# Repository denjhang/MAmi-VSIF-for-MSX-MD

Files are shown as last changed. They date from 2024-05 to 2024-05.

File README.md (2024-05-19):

# MAmi-VSIF for MSX+MD
 The open source hardware implementation of the VSIF standard can be completed using the red FT232 module that can be easily purchased on Alex. No complicated welding is required. The current hardware supports both MSX and MD devices.    
 The currently supported software is VGM player and MamidiMEMO. For details, see here:   
 https://github.com/110-kenichi/mame  
## Connect to 1ChipMSX (clone)  
The latest version of the vgmplay program fully supports 1ChipMSX's PSG+OPLL+SCC1, but it needs to be used in a certain order to be used normally. First use mini usb to connect to the FTDI module, then open vgmplay. At this time, first check whether the words "usb serial port (com7)" appear in the device manager. If not, you need to install the driver.  
  
After the computer correctly recognizes FTDI, the next step is to open your 1ChipMSX, and then use sofarun to open VGMPlay_msx.rom and run the rom according to the default settings.  
At this time, msx will have a black screen background with "MAMI VGM Sound Driver", and then you can see that the OPLL and SCC of your 1ChipMSX have been correctly recognized and the device location is displayed. At this time, plug the DB9 female connector of VSIF into the JoyPort2 of 1ChipMSX, and the connection is successful without pressing any buttons.  
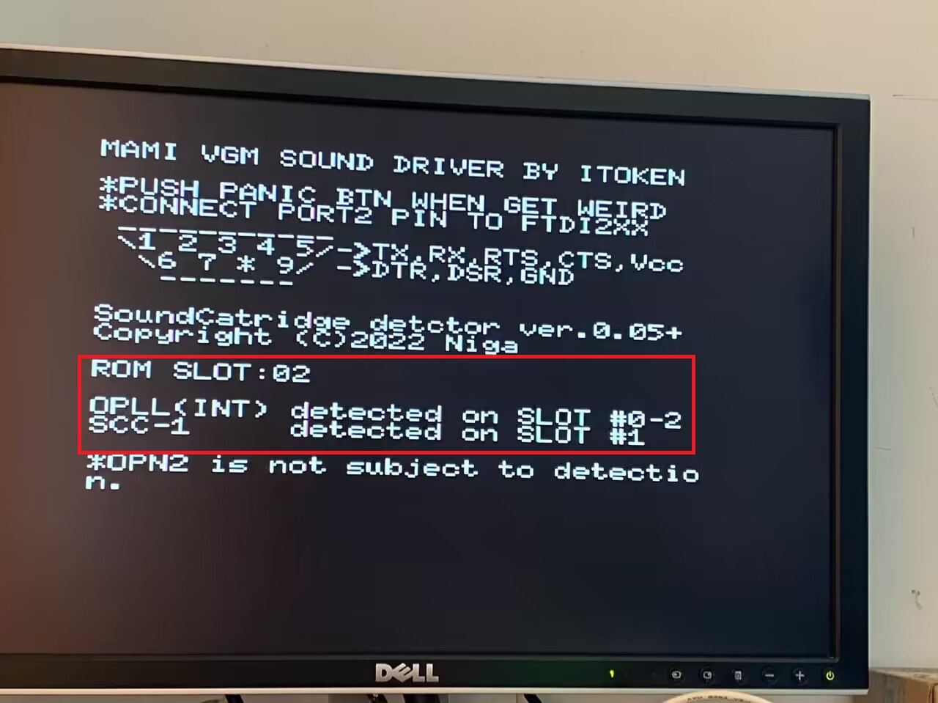
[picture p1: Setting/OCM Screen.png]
  
Then set the VSIF Checker according to the picture method. After the setting is completed, you can drag the vgm file into the VSIF Checker playlist. If the playback is very stuck, you need to adjust the FTDI CLK. I recommend adjusting it to 7/5/5. The playback speed is related to the length of the USB cable. It is not recommended to use a USB cable that is too long.    
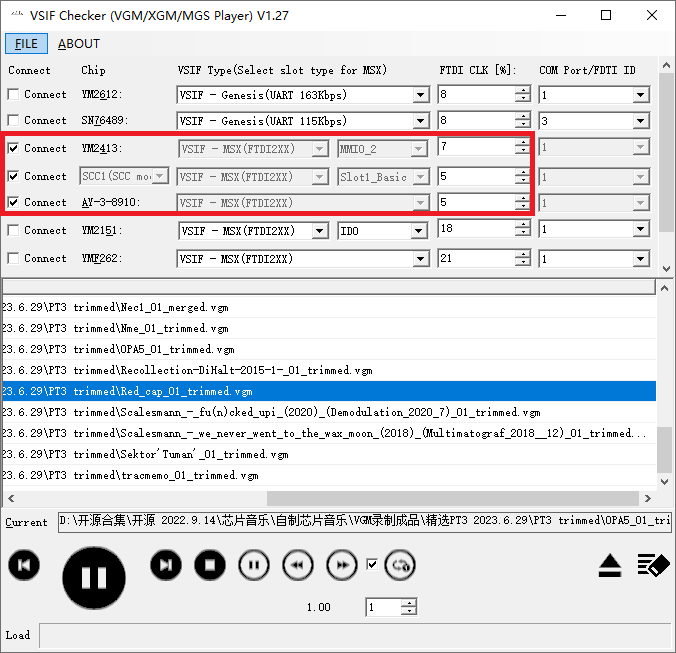
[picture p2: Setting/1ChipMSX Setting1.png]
    
It is best to use a new mini usb cable and avoid using old or rusty cables. Theoretically, the shorter the length of the USB cable, the faster the VSIF data transfer rate.

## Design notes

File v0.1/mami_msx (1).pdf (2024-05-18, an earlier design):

本書 PDF file

MSX / PC-6001 シリーズ対応 VGM Sound Interface
MAmi-VSIF dongle for MSX 使用説明書
猫の手リモコンもよろしく！ | Produced by にが HP
ご注意 | 本機は同人ハードウエアです。

ご使用には MSX または PC-6001 シリー

ズ本体と Windows10 以降の PC が必要
です。アフターサポートはありませんの
でご了承の上お求めください。
概要
MAmidiMEmo はレトロ PC やレトロゲーム、チッ プチューンなどで使われている FM 音源や PSG 音源 などを鳴らす事ができる Windows 用のソフトウエア MIDI 音源で、お使いの DAW や MIDI シーケンサー、 MIDI キーボードなどから FM 音源や PSG 音源を簡 単に鳴らすことが可能です。さらに、MAmidiMEmo が対応する実音源と PC とを USB で接続することで、 ソフトウエア音源の代わりに実音源を鳴らすことが
可能です。

本機は MSX/PC-6001 対応の MAmidiMEmo VGM

Sound Interface(VSIF)ドングルです。MSX/P6 に内 蔵、または接続された実音源を WindowsPC からデー タを流し込むことで発音させることができます。多数
の音源デバイスに対応しており、実音源による VGM
再生をお手軽にお楽しみいただけます。
対応機種

・MSX / PC-6001 シリーズ

・Windows10 以降の PC (32bit / 64bit 版）

MSX では MSX-DOS が動作する環境、または適当 な FlashROM カートリッジが必要です。
Windows8.1 以前の OS での動作は保証しません。

対応音源

・MSX 本体内蔵 PSG , MSX-MUSIC (OPLL)

・FMPAC (OPLL) , Konami SCC / SCC-I

・YAMAHA SFG-01 / SFG-05 (OPM)

・MSX-AUDIO (Y8950)

・Makoto compatible cartridge (OPNA)

・MusicalMemoryMapper (DCSG)

・似非 OPL3-RAM (OPL3)

・P6 本体内蔵 PSG , P6SR 内蔵 YM2203 (OPN)

・PC-60m55 cartridge (OPN)

・似非 P6ROM (OPN2)

各部の名称

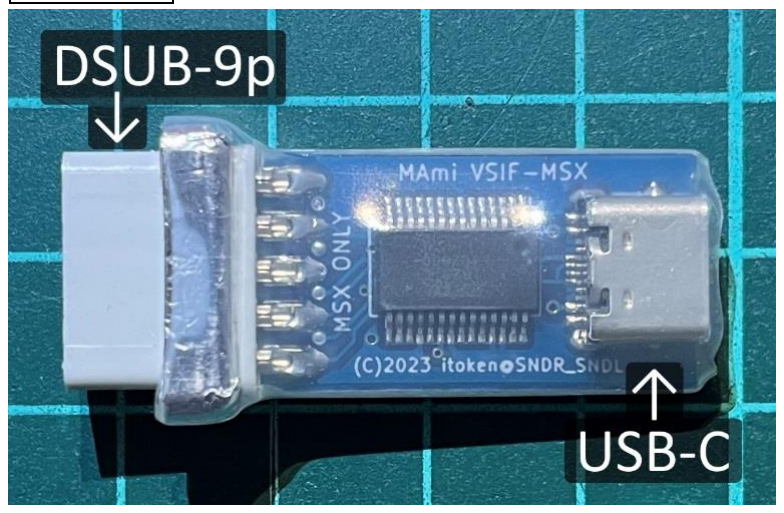
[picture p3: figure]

データ通信に対応した USB 2.0 Type-C ケーブルを別

途用意してください。

デバイス接続と FTDI ドライバのインストール
MSX/P6 に対応音源カートリッジを挿入し、本機を ジョイスティックポートに接続してください。MSX
では Port 2 に、P6 では Port 1 に接続します。

本機の USB-C コネクタと WindowsPC の USB 2.0 ポートをケーブル接続し、MSX/P6 の電源を投入する と、Windows が本機をシリアルポートデバイスとし て認識し、ドライバの自動インストールが行われます。

本機の電源は MSX/P6 から供給されます。そのため 本機を PC に接続しただけでは認識されません。

MAmidiMEmo アプリケーションのインストール 下記 URL から最新版の MAmidiMEmo パッケージ をダウンロードし、WindowsPC の適当なフォルダに 展開してください。

https://github.com/110-kenichi/mame/releases

MAmidiMEmo の動作には NET Framework 4.7 以

降と VC++2012 Runtime が必要です。

MAmi-VGM ドライバの起動

1) MSX-DOS から起動する場合
展開した MAmidiMEmo パッケージに含まれる 「VGM_msx.rom」と当方の製品サポートページ

http://niga2.sytes.net/sp/ から ダ ウ ン ロ ー ド した

「NGLOAD.COM」を MSX-DOS ディスクにコピー してください。MSX-DOS を起動し、下記コマンドを 実行すると MAmi-VGM ドライバが起動します。

NGLOAD VGM_MSX.ROM

2) MSX FlashROM から起動する場合

MAmidiMEmo パッケージ内の「VGM_msx.rom」 をお手持ちの FlashROM カートリッジに書き込み、 MSX スロットに挿入して電源を入れると自動的に

MAmi-VGM ドライバが起動します。FlashROM はな るべく番号の若いスロットに挿してください。

SoundCoreSLOT EX の内部拡張スロット#X-3 の FlashROM にインストールして運用することもでき

ます。この場合は「VGM_msx_Vkey.rom」を書き込 んでください。Vkey 版の ROM を使用した場合は MSX 起動時に V キーを押しっぱなしにすることで MAmi-VGM ドライバが起動します。V キーを押さな ければドライバの起動はスキップされます。

FlashROM デバイスへのインストール手順につい ては各製品のマニュアルを参照してください。

3) PC-6001 テープ（CMT）から LOAD する場合 PC の音声出力と PC-6001 の CMT 入力端子をケー

ブルで接続してください。PC-6001 を Mode1,Page1 で起動し、 CLOAD コマンド を実行 します。

MAmidiMEmoパッケージ内の「VGM_P6T_01.WAV」 を PC で再生し、LOAD が終わったら RUN します。

引き続き PC で「VGM_P6T_02.WAV」を再生し、 LOAD が完了すると MAmi-VGM ドライバが起動し ます。OPN 楽曲データを再生するデバイスの選択メ
ニューが表示されますので数字キーで選択すると画
面が消去され、VGM データ待ちとなります。

PSG 音源のみ接続されている場合は 1 を選択して ください。ロードに失敗する場合は PC の音声出力を 大きめに設定してやり直してください。

4) PC-6001 似非 P6ROM から起動する場合
PC で展開した MAmidiMEmo パッケージに含まれ

る「VGM_P6.ROM」を似非 P6ROM の FlashROM に書き込んで P6 のスロットに挿入し、電源を投入し てください。OPN 楽曲データを再生するデバイスの
選択メニューが表示されますので、数字キーで選択す
ると画面が消えて VGM データ待ちとなります。

VGM_P6.ROM を「戦士のカートリッジ」に書き込 んで運用することもできます。
各デバイスへの ROM ファイルの書き込み手順につ
いては製品のマニュアルを参照してください。

VGMPlayer の起動と VGM ファイルの再生

WindowsPC で VGMPlayer を起動し、GUI 画面に

て使用音源の VSIF Type を VSIF-MSX/PC-6001

(FTDI2XX)にして Connect します。このとき FTDI

CLK[%] =25、FTDI/COM No =1 に、FTDI Div ofst =0 に設定してください。Conn にチェックが入らない場 合は本機が正しく認識されていませんので、接続やド
ライバを確認してください。ファイルエリアにお好み
の VGM ファイルを登録して▶ボタンを押下すると再 生が始まります。演奏がもたつく場合は、FTDI
CLK[%]を少しずつ小さくします。発音されない場合 は MSX/P6 の再起動からやり直してください。

詳細は下記マニュアルを参してください。

https://github.com/110-kenichi/mame/blob/master

/docs/MAmidiMEmo/Manual.pdf (https://github.com/110-kenichi/mame/blob/master/docs/MAmidiMEmo/Manual.pdf)
技術情報

USB I/F : FT245RL (asynchronous bit bang mode)

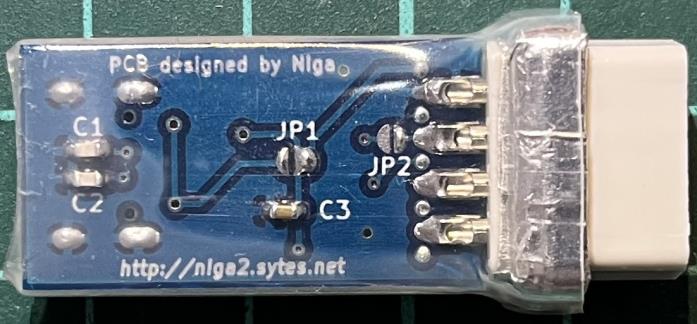
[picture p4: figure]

JP1 | 左 Close で USB から給電 右 Close で DSUB から給電 (default)
JP2 | Close で FT245RL-10p と DSUB-8p が接続 （default は Open）

FTDI CLK[%]や FTDI Div ofst の最適値には個体差 があります。いずれも数値が小さい方が高速です。

・謝辞ほか

itoken さん、MAmi-VGMPlayer の各種音源対応や

技術情報のご提供など、多大なるご協力ありがとうござ
いました。TINY 野郎さん、れふてぃさん、ゆうくんさ ん、ご協力ありがとうございました。

VGM Sound Interface（VSIF）は itoken さん発案に

よる音源デバイス用データ通信フォーマットです。
作者の WEB サイト

http://niga2.sytes.net 自宅サーバーのた

め時々落ちていることがあります。お問い

合わせは作者サイトの BBS か blog からお願いします。

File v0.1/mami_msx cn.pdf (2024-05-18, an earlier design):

### MSX 的 MAmi-VSIF 加密狗使⽤⼿册

概述

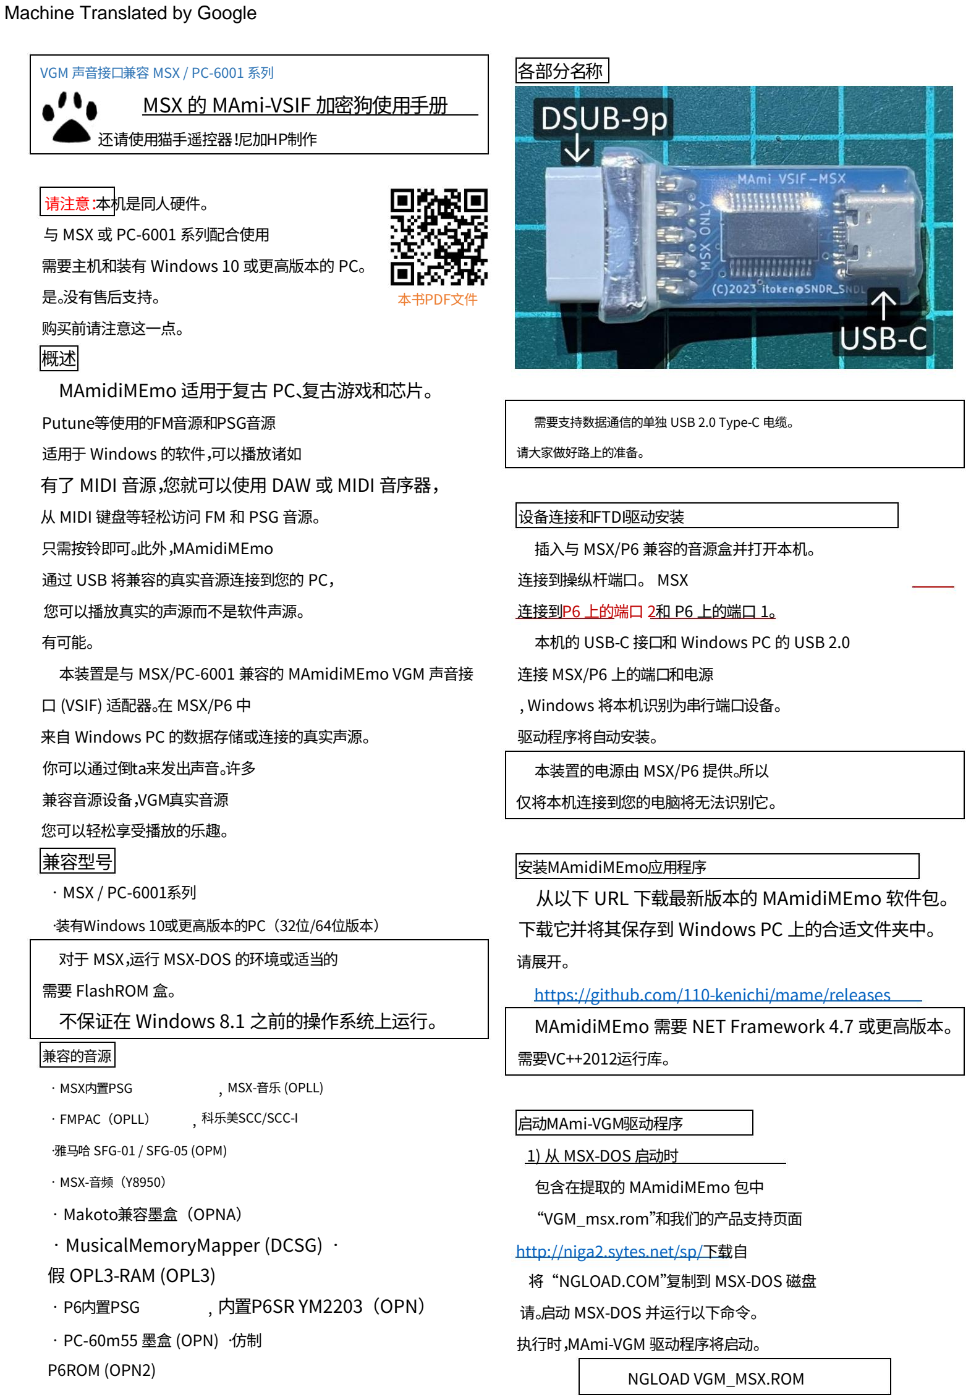
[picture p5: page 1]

本书PDF⽂件

需要⽀持数据通信的单独 USB 2.0 Type-C 电缆。

•FMPAC（OPLL）

,

,

请⼤家做好路上的准备。

科乐美SCC/SCC-I

•雅⻢哈 SFG-01 / SFG-05 (OPM)

•MSX-⾳频（Y8950）

•MSX内置PSG | MSX-⾳乐 (OPLL)

VGM 声⾳接⼝兼容 MSX / PC-6001 系列

http://niga2.sytes.net/sp/下载⾃

连接 MSX/P6 上的端⼝和电源

需要VC++2012运⾏库。

本装置的电源由 MSX/P6 提供。所以

有了 MIDI ⾳源，您就可以使⽤ DAW 或 MIDI ⾳序器，

内置P6SR YM2203（OPN）

需要 FlashROM 盒。

与 MSX 或 PC-6001 系列配合使⽤

连接到操纵杆端⼝。 MSX

Putune等使⽤的FM⾳源和PSG⾳源

•Makoto兼容墨盒（OPNA）

, Windows 将本机识别为串⾏端⼝设备。

### 下载它并将其保存到 Windows PC 上的合适⽂件夹中。

将“NGLOAD.COM”复制到 MSX-DOS 磁盘

安装MAmidiMEmo应⽤程序

本装置是与 MSX/PC-6001 兼容的 MAmidiMEmo VGM 声⾳接

⼝ (VSIF) 适配器。在 MSX/P6 中

,

仅将本机连接到您的电脑将⽆法识别它。

从 MIDI 键盘等轻松访问 FM 和 PSG ⾳源。

•MusicalMemoryMapper (DCSG) • 假 OPL3-RAM (OPL3)

请展开。

不保证在 Windows 8.1 之前的操作系统上运⾏。

连接到P6 上的端⼝ 2和 P6 上的端⼝ 1。

需要主机和装有 Windows 10 或更⾼版本的 PC。

启动MAmi-VGM驱动程序

您可以播放真实的声源⽽不是软件声源。

驱动程序将⾃动安装。

适⽤于 Windows 的软件，可以播放诸如

•MSX / PC-6001系列

执⾏时，MAmi-VGM 驱动程序将启动。

您可以轻松享受播放的乐趣。

### 各部分名称

MAmidiMEmo 适⽤于复古 PC、复古游戏和芯⽚。

只需按铃即可。此外，MAmidiMEmo

包含在提取的 MAmidiMEmo 包中

有可能。

是。没有售后⽀持。

兼容的⾳源

你可以通过倒ta来发出声⾳。许多

•P6内置PSG

https://github.com/110-kenichi/mame/releases

设备连接和FTDI驱动安装

还请使⽤猫⼿遥控器！尼加HP制作

1) 从 MSX-DOS 启动时

•装有Windows 10或更⾼版本的PC（32位/64位版本）

NGLOAD VGM_MSX.ROM

### 兼容型号

通过 USB 将兼容的真实⾳源连接到您的 PC，

•PC-60m55 墨盒 (OPN) •仿制

P6ROM (OPN2)

“VGM_msx.rom”和我们的产品⽀持⻚⾯

本机的 USB-C 接⼝和 Windows PC 的 USB 2.0

购买前请注意这⼀点。

对于 MSX，运⾏ MSX-DOS 的环境或适当的

MAmidiMEmo 需要 NET Framework 4.7 或更⾼版本。

兼容⾳源设备，VGM真实⾳源

请。启动 MSX-DOS 并运⾏以下命令。

从以下 URL 下载最新版本的 MAmidiMEmo 软件包。

来⾃ Windows PC 的数据存储或连接的真实声源。

插⼊与 MSX/P6 兼容的⾳源盒并打开本机。

请注意：本机是同⼈硬件。

## Machine Translated by Google

## Machine Translated by Google

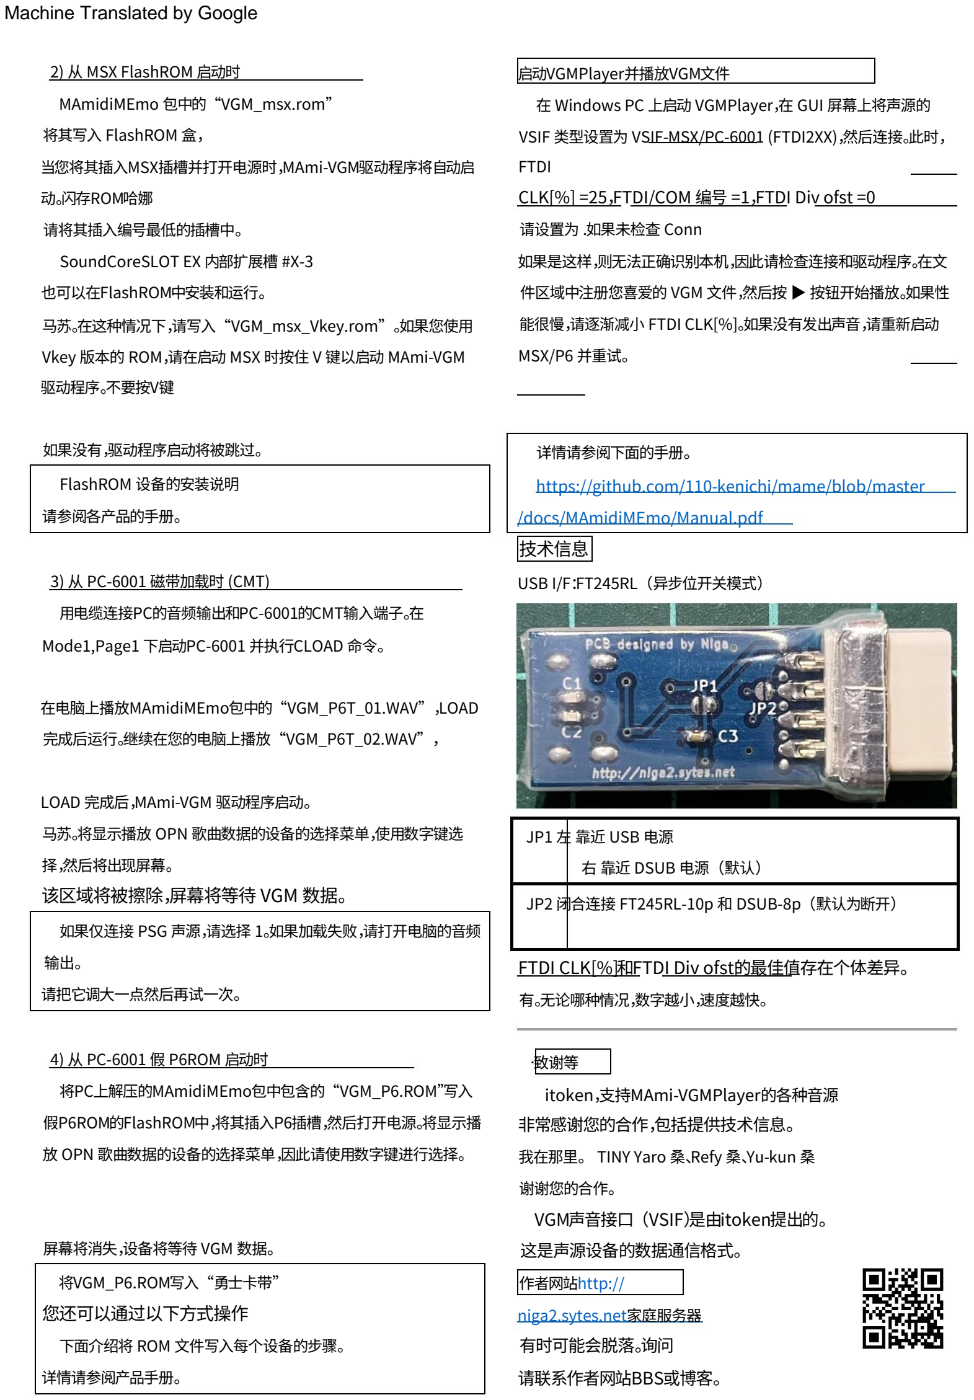
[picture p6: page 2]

itoken，⽀持MAmi-VGMPlayer的各种⾳源

### 有时可能会脱落。询问

### 请联系作者⽹站BBS或博客。

### ⾮常感谢您的合作，包括提供技术信息。

### 这是声源设备的数据通信格式。

VGM声⾳接⼝（VSIF）是由itoken提出的。

FTDI CLK[%]和FTDI Div ofst的最佳值存在个体差异。

⻢苏。在这种情况下，请写⼊“VGM_msx_Vkey.rom”。如果您使⽤

Vkey 版本的 ROM，请在启动 MSX 时按住 V 键以启动 MAmi-VGM

驱动程序。不要按V键

启动VGMPlayer并播放VGM⽂件

3) 从 PC-6001 磁带加载时 (CMT)

谢谢您的合作。

作者⽹站http://

niga2.sytes.net家庭服务器

请把它调⼤⼀点然后再试⼀次。

当您将其插⼊MSX插槽并打开电源时，MAmi-VGM驱动程序将⾃动启

动。闪存ROM哈娜

FlashROM 设备的安装说明

在电脑上播放MAmidiMEmo包中的“VGM_P6T_01.WAV”，LOAD

完成后运⾏。继续在您的电脑上播放“VGM_P6T_02.WAV”，

⻢苏。将显⽰播放 OPN 歌曲数据的设备的选择菜单，使⽤数字键选

择，然后将出现屏幕。

请设置为 .如果未检查 Conn

详情请参阅下⾯的⼿册。

如果是这样，则⽆法正确识别本机，因此请检查连接和驱动程序。在⽂

件区域中注册您喜爱的 VGM ⽂件，然后按 ▶ 按钮开始播放。如果性

能很慢，请逐渐减⼩ FTDI CLK[%]。如果没有发出声⾳，请重新启动

MSX/P6 并重试。

将其写⼊ FlashROM 盒，

4) 从 PC-6001 假 P6ROM 启动时

屏幕将消失，设备将等待 VGM 数据。

### 您还可以通过以下⽅式操作

右 靠近 DSUB 电源（默认）

2) 从 MSX FlashROM 启动时

⽤电缆连接PC的⾳频输出和PC-6001的CMT输⼊端⼦。在

Mode1,Page1 下启动PC-6001 并执⾏CLOAD 命令。

在 Windows PC 上启动 VGMPlayer，在 GUI 屏幕上将声源的

VSIF 类型设置为 VSIF-MSX/PC-6001 (FTDI2XX)，然后连接。此时，

FTDI

如果没有，驱动程序启动将被跳过。

SoundCoreSLOT EX 内部扩展槽 #X-3

/docs/MAmidiMEmo/Manual.pdf (https://github.com/110-kenichi/mame/blob/master/docs/MAmidiMEmo/Manual.pdf)

如果仅连接 PSG 声源，请选择 1。如果加载失败，请打开电脑的⾳频

输出。

详情请参阅产品⼿册。

USB I/F：FT245RL（异步位开关模式）

JP2 闭合连接 FT245RL-10p 和 DSUB-8p（默认为断开）

请参阅各产品的⼿册。

CLK[%] =25，FTDI/COM 编号 =1，FTDI Div ofst =0

LOAD 完成后，MAmi-VGM 驱动程序启动。

有。⽆论哪种情况，数字越⼩，速度越快。

我在那⾥。 TINY Yaro 桑、Refy 桑、Yu-kun 桑

将PC上解压的MAmidiMEmo包中包含的“VGM_P6.ROM”写⼊

假P6ROM的FlashROM中，将其插⼊P6插槽，然后打开电源。将显⽰播

放 OPN 歌曲数据的设备的选择菜单，因此请使⽤数字键进⾏选择。

•致谢等

https://github.com/110-kenichi/mame/blob/master

请将其插⼊编号最低的插槽中。

JP1 左 靠近 USB 电源

将VGM_P6.ROM写⼊“勇⼠卡带”

下⾯介绍将 ROM ⽂件写⼊每个设备的步骤。

也可以在FlashROM中安装和运⾏。

### 技术信息

MAmidiMEmo 包中的“VGM_msx.rom”

### 该区域将被擦除，屏幕将等待 VGM 数据。

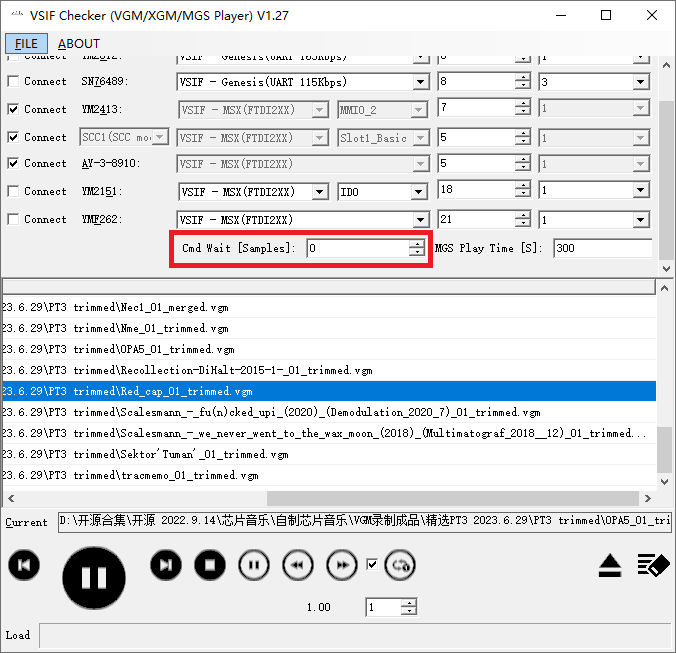
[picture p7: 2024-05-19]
Setting/1ChipMSX Setting2.png

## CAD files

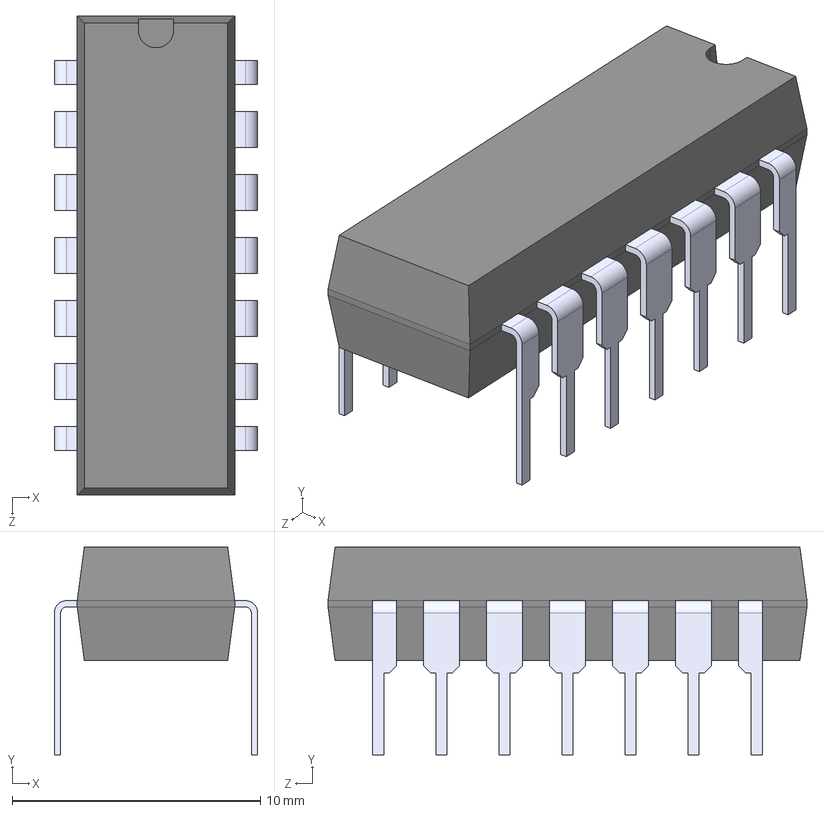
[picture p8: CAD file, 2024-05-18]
NES_MAmi/SN74LS00NE4/SN74LS00NE4.step
8.19 x 8.38 x 19.3 mm

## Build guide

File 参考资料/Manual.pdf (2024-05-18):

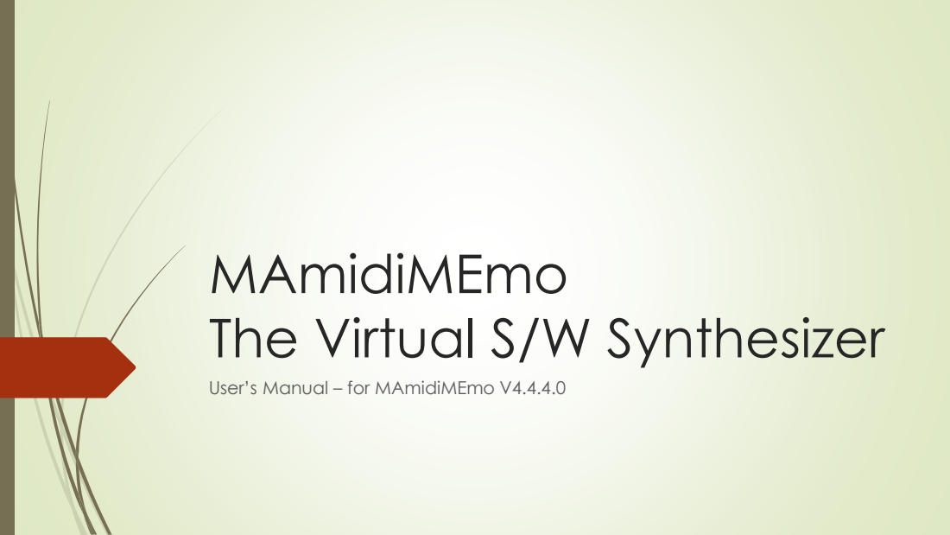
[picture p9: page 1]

MAmidiMEmo
The Virtual S/W Synthesizer

User’s Manual – for MAmidiMEmo V4.4.4.0

# What is the MAmidiMEmo?

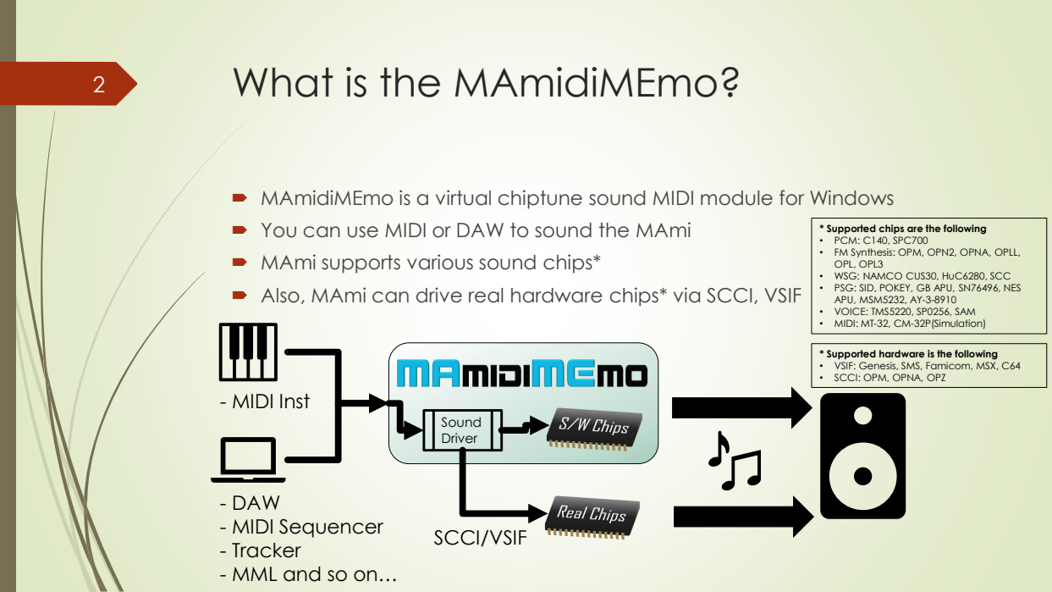
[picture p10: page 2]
- MIDI Inst; Sound Driver; SCCI/VSIF

MAmidiMEmo is a virtual chiptune sound MIDI module for Windows
You can use MIDI or DAW to sound the MAmi
MAmi supports various sound chips*
Also, MAmi can drive real hardware chips* via SCCI, VSIF

* Supported chips are the following
• PCM: C140, SPC700
• FM Synthesis: OPM, OPN2, OPNA, OPLL,
OPL, OPL3
• WSG: NAMCO CUS30, HuC6280, SCC
• PSG: SID, POKEY, GB APU, SN76496, NES
APU, MSM5232, AY-3-8910
• VOICE: TMS5220, SP0256, SAM
• MIDI: MT-32, CM-32P(Simulation)

* Supported hardware is the following
• VSIF: Genesis, SMS, Famicom, MSX, C64
• SCCI: OPM, OPNA, OPZ

- DAW
- MIDI Sequencer
- Tracker
- MML and so on…

# Install & Basic Settings

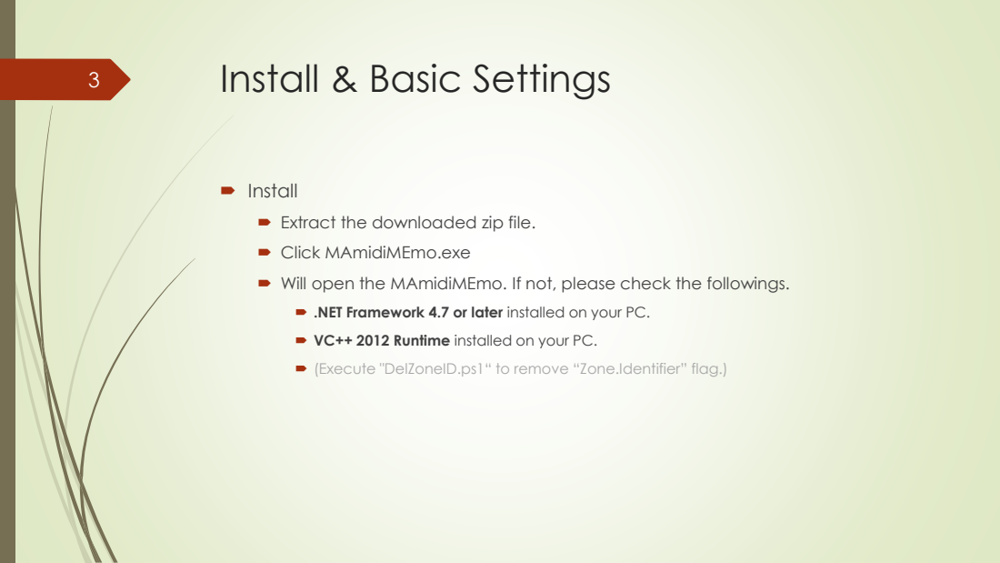
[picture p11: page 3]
Install

Extract the downloaded zip file.
Click MAmidiMEmo.exe
Will open the MAmidiMEmo. If not, please check the followings.

.NET Framework 4.7 or later installed on your PC.

VC++ 2012 Runtime installed on your PC.

(Execute "DelZoneID.ps1“ to remove “Zone.Identifier” flag.)

# Window Overview

# Add and Remove a Chip

To add
Select the chip
from this menu.

# Edit chip and sound parameters

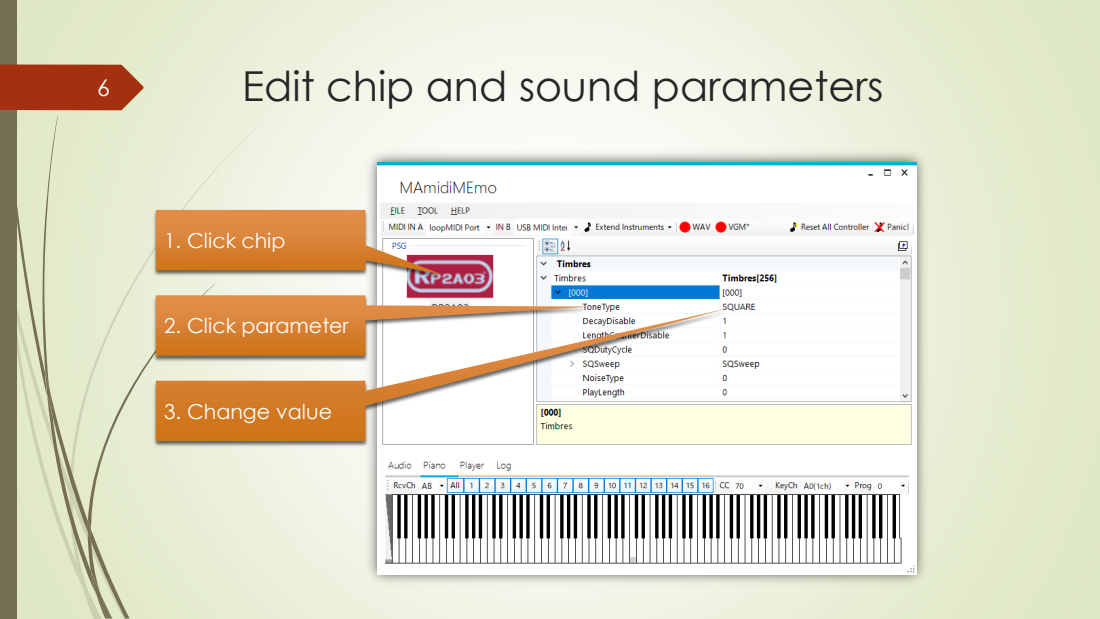
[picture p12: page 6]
1. Click chip; 2. Click parameter; 3. Change value

Between MIDI ch and Chip ch Relation.

You don’t need to concern the Chip ch. , generally.
MAmidiMEmo will assign suitable Chip ch. automatically.
However, you need to concern a max ch. number of the Chip.
MAmidiMEmo will assign oldest sounding ch. to sound the new sounds.

MAmidiMemo will assign
empty ch. or oldest
sounsing ch. , generally.

# Sounding Structure

MAmidiMEmo outputs a sound from MIDI message along with the following
structure.
So, at least, you need to edit the Timbre parameters to sound something.

# Timbre

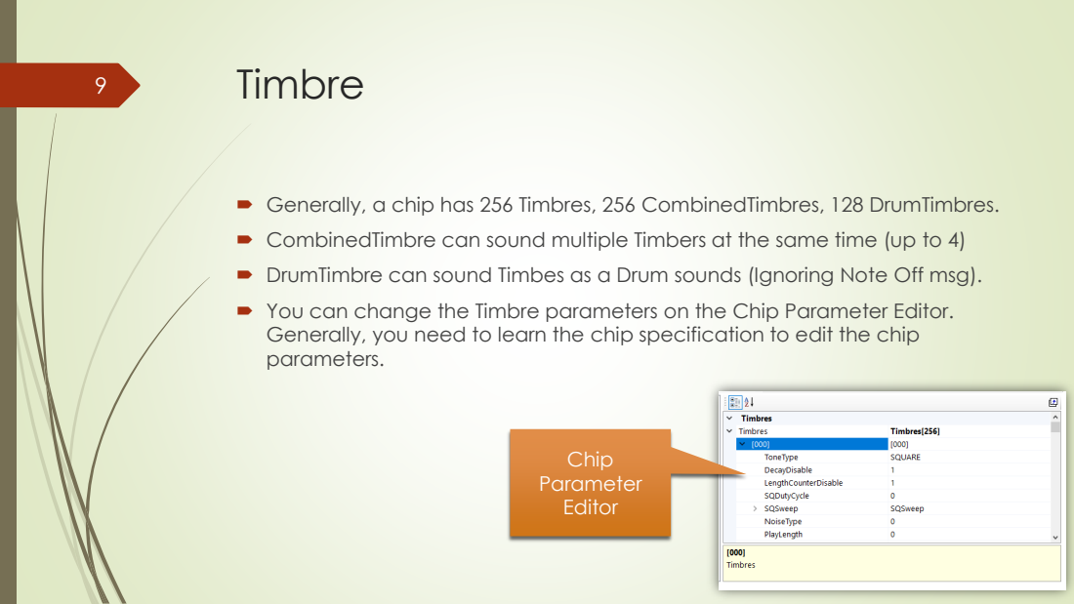
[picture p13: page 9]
Chip Parameter Editor

Generally, a chip has 256 Timbres, 256 CombinedTimbres, 128 DrumTimbres.
CombinedTimbre can sound multiple Timbers at the same time (up to 4)
DrumTimbre can sound Timbes as a Drum sounds (Ignoring Note Off msg).
You can change the Timbre parameters on the Chip Parameter Editor.
Generally, you need to learn the chip specification to edit the chip
parameters.

# Timbre Structure

Sound params are H/W settings.
See the chip manual for more

FM Op parameters

Timbre

Driver params are
the MAmidiMEmo
settings.

Fx & Env parameter

# Driver parameters - Fx & Env Structure

You can make for a rich sound by using driver params.
Especially, FxS can do it.

Fx & Env parameter

Click here to open
the GUI Editor.

# Sample sounds

There are sample sound files in the “Samples” folder. You can drop a
sample file “*.MAmi" to the left pane.

# Additional files

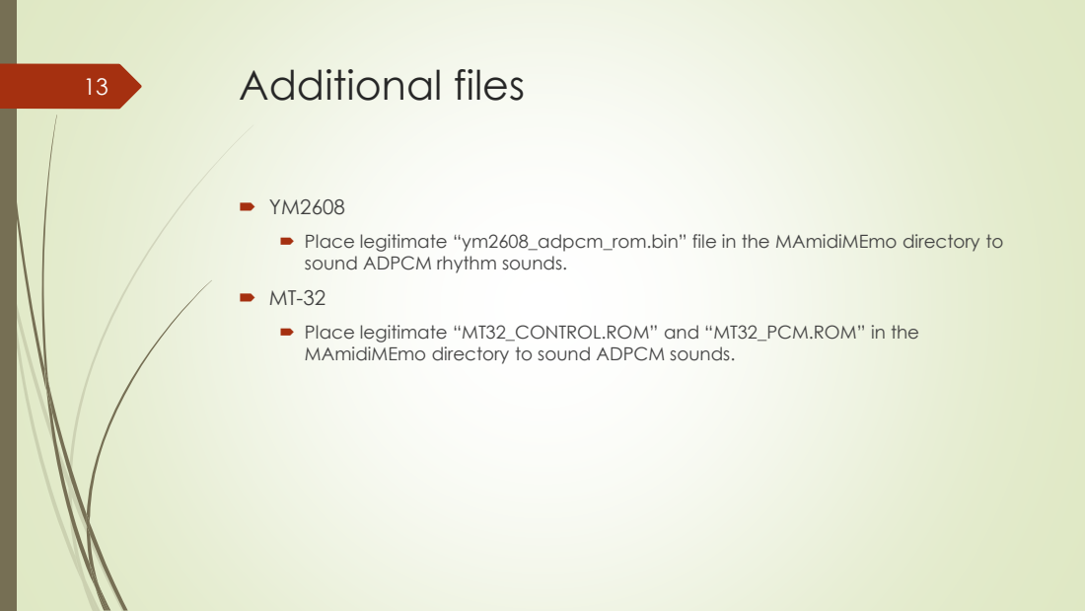
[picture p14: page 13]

Place legitimate “ym2608_adpcm_rom.bin” file in the MAmidiMEmo directory to
sound ADPCM rhythm sounds.

Place legitimate “MT32_CONTROL.ROM” and “MT32_PCM.ROM” in the
MAmidiMEmo directory to sound ADPCM sounds.

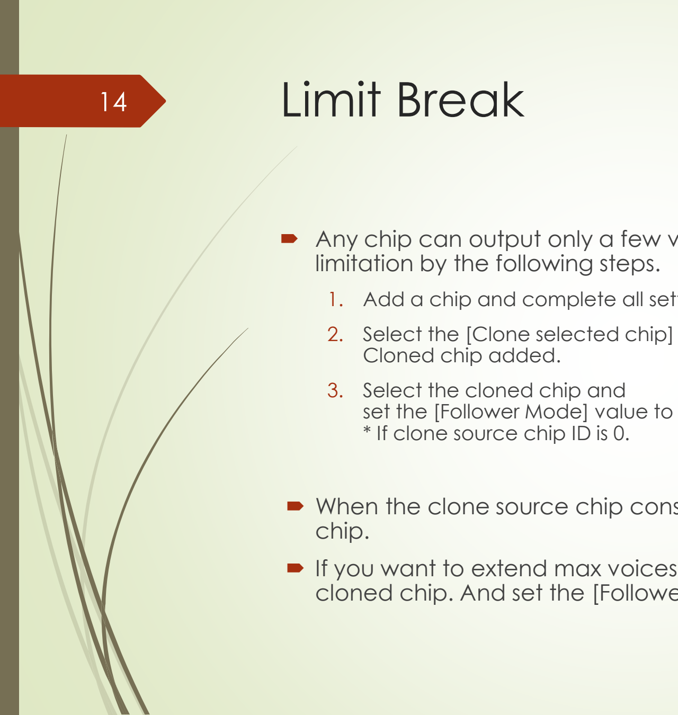
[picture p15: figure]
Limit Break; limitation by the following steps.; 2. Select the [Clone selected chip] Cloned chip added.; 3. Select the cloned chip and; * If clone source chip ID is 0.; chip.

- Any chip can output only a few voices. However, MAmidiMEmo can break this
1. Add a chip and complete all settings the chip.

set the [Follower Mode] value to “Unit0*”.

- When the clone source chip consumed all voices, the cloned chip sound for the
- If you want to extend max voices more, select the [Clone selected chip] of the cloned chip. And set the [Follower Mode] value to “Unit0”.

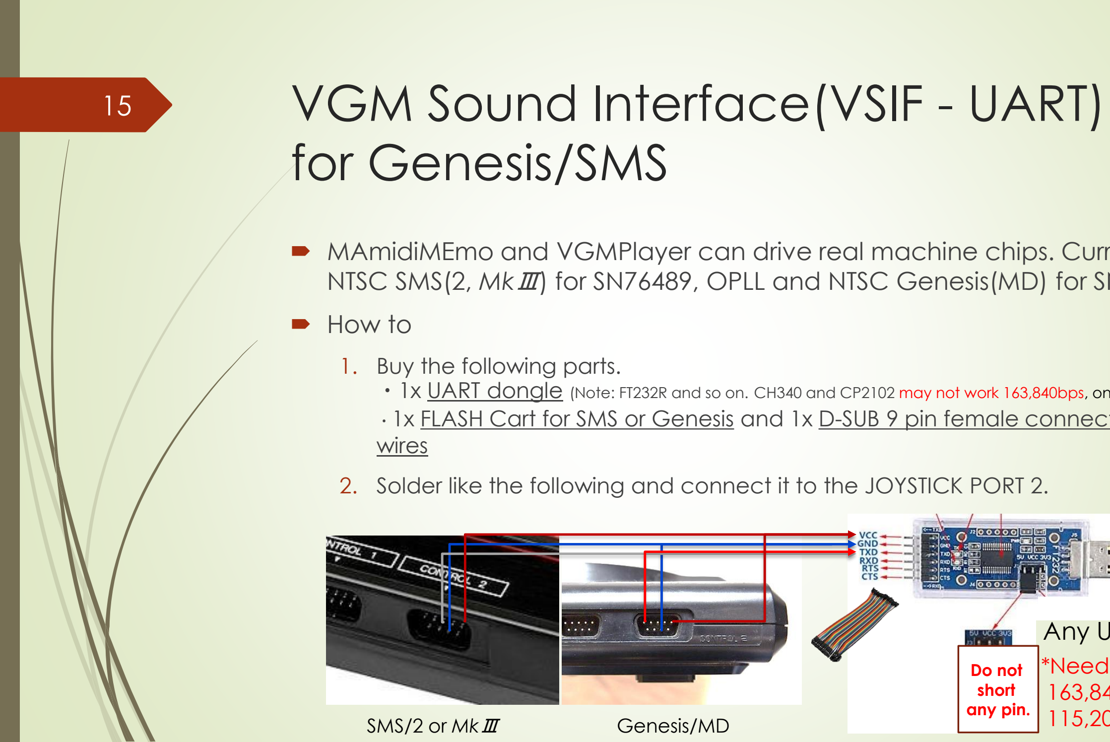
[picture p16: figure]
VGM Sound Interface(VSIF - UART) for Genesis/SMS; How to; 1. Buy the following parts.; wires; SMS/2 or MkⅢ; Genesis/MD; Do not short any pin.

- MAmidiMEmo and VGMPlayer can drive real machine chips. Currently supports NTSC SMS(2, MkⅢ) for SN76489, OPLL and NTSC Genesis(MD) for SN76489, OPN2.

・1x UART dongle (Note: FT232R and so on. CH340 and CP2102 may not work 163,840bps, only 115,200bps.)
・1x FLASH Cart for SMS or Genesis and 1x D-SUB 9 pin female connector and DuPont
2. Solder like the following and connect it to the JOYSTICK PORT 2.

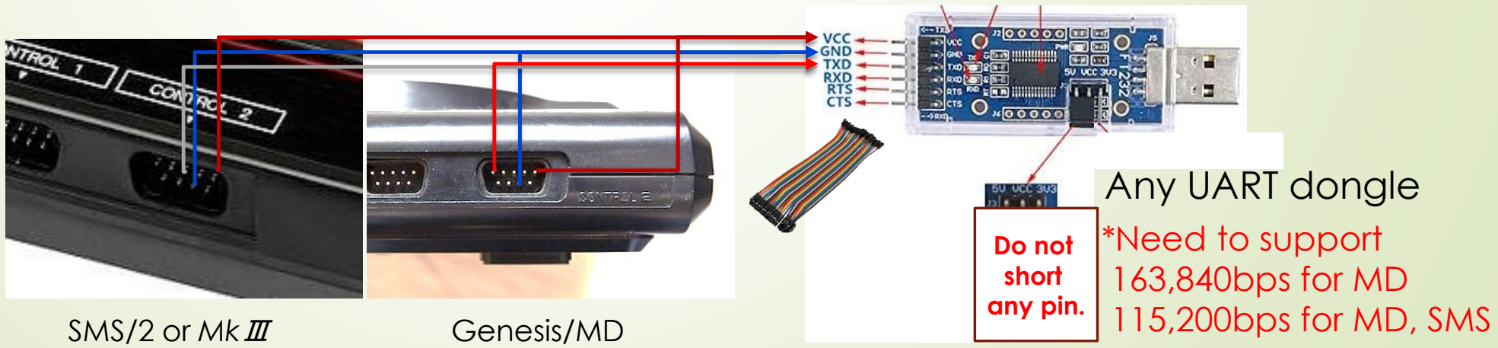
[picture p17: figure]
*Need to support 163,840bps for MD 115,200bps for MD, SMS; Any UART dongle

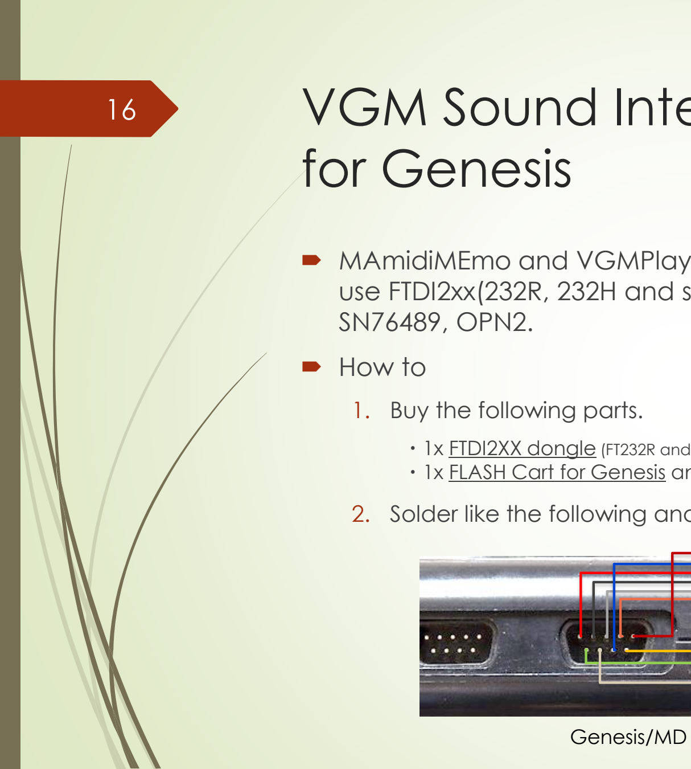
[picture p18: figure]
for Genesis; SN76489, OPN2.; How to; 1. Buy the following parts.; Genesis/MD

# VGM Sound Interface(VSIF - FTDI)

- MAmidiMEmo and VGMPlayer can drive real machine chips more faster if you use FTDI2xx(232R, 232H and so on). Currently supports NTSC Genesis(MD) for

・1x FTDI2XX dongle (FT232R and so on. Need to support 5V.)
・1x FLASH Cart for Genesis and 1x D-SUB 9 pin female connector and DuPont wires

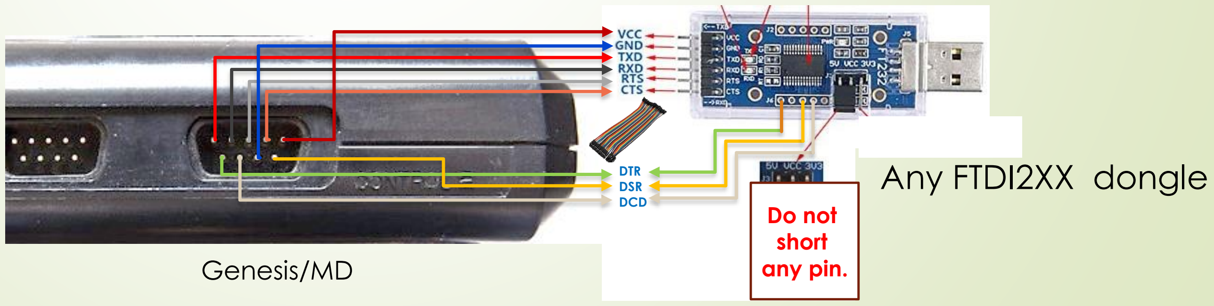
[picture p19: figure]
Any FTDI2XX dongle DTR DSR DCD; Do not short any pin.

2. Solder like the following and connect it to the JOYSTICK PORT 2.

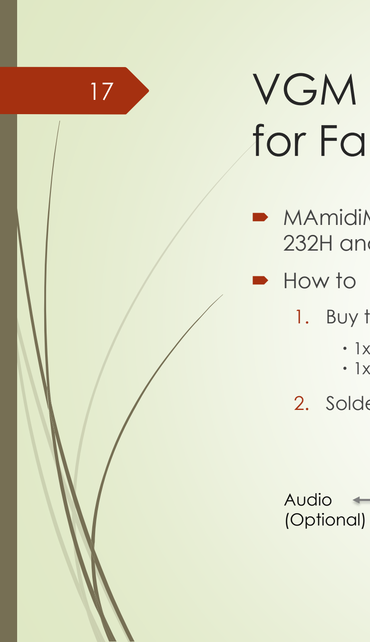
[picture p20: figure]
How to; Audio (Optional)

# VGM Sound Interface(VSIF - FTDI) for Famicom

- MAmidiMEmo can drive real machine chips more faster if you use FTDI2xx(232R, 232H and so on). Currently supports NTSC Famicom and RP2A03(No DAC)/FDS/VRC6.
1. Buy the following parts.

・1x FTDI2XX dongle (FT232R and so on. Need to support 5V.)
・1x FLASH Cart for Famicom and 1x D-SUB 15 pin female connector for FC and DuPont wires
2. Solder like the following.

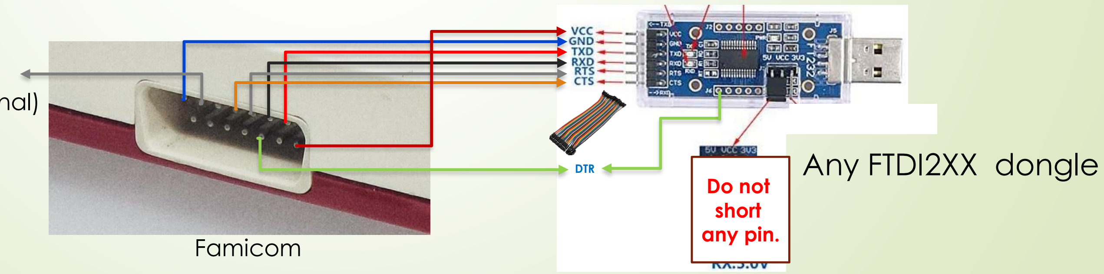
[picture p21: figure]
Famicom; DTR; Any FTDI2XX dongle; Do not short any pin.

# VGM Sound Interface(VSIF - FTDI)

- MAmidiMEmo can drive real MSX machine chips if you use FTDI2xx(232R, 232H and so on). Currently supports NTSC MSX for AY-3-8910 and OPLL and SCC+ and OPL3.
NOTE: Be sure to select proper SLOT# for SCC to use SCC.
Set FTDI clk value to 17~ for each chip.
1. Buy the following parts.

・1x FTDI2XX dongle (FT232R and so on. Need to support 5V.)
・1x D-SUB 9 pin female connector and DuPont wires

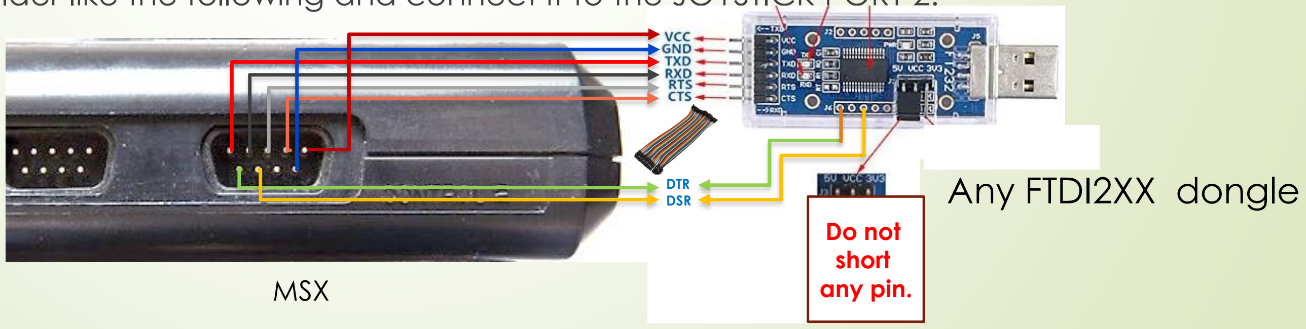
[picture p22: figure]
MSX; Any FTDI2XX dongle DTR DSR; Do not short any pin.

2. Solder like the following and connect it to the JOYSTICK PORT 2.

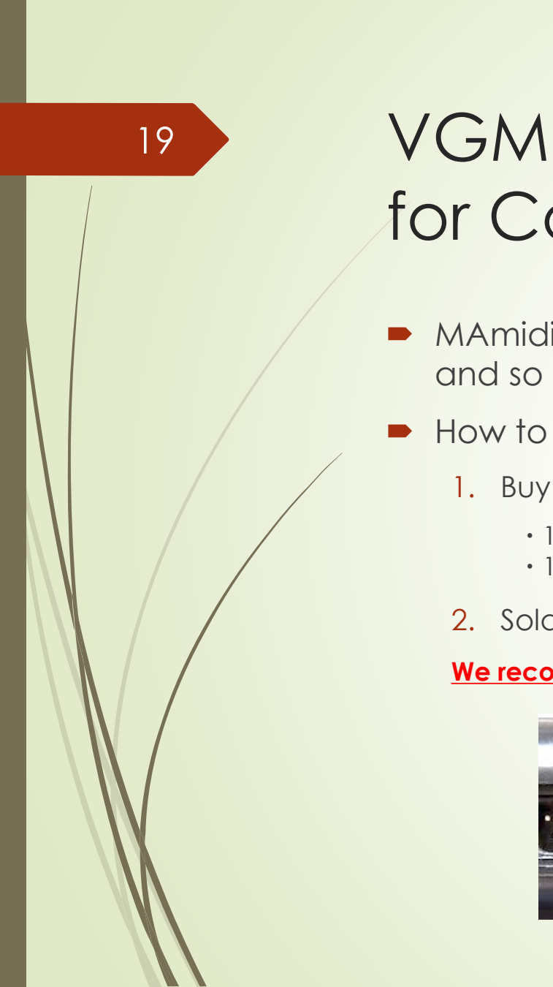
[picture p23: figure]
How to

# VGM Sound Interface(VSIF - FTDI) for Commodore 64(C64)

- MAmidiMEmo can drive real MSX machine chips if you use FTDI2xx(232R, 232H and so on). Currently supports NTSC/PAL C64 for SIDs.
1. Buy the following parts.

・1x FTDI2XX dongle (FT232R and so on. Need to support 5V.)
・1x D-SUB 9 pin female connector and DuPont wires
2. Solder like the following and connect it to the JOYSTICK PORT 2.

We recommend to use ARMSID with ADSR bud fixing.

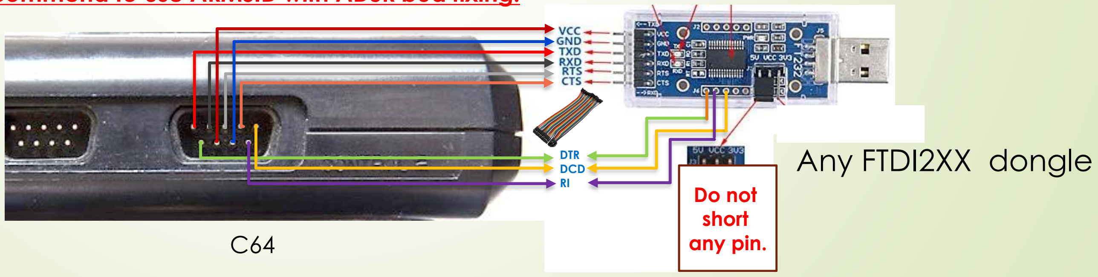
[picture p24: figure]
Any FTDI2XX dongle DTR DCD RI; Do not short any pin.

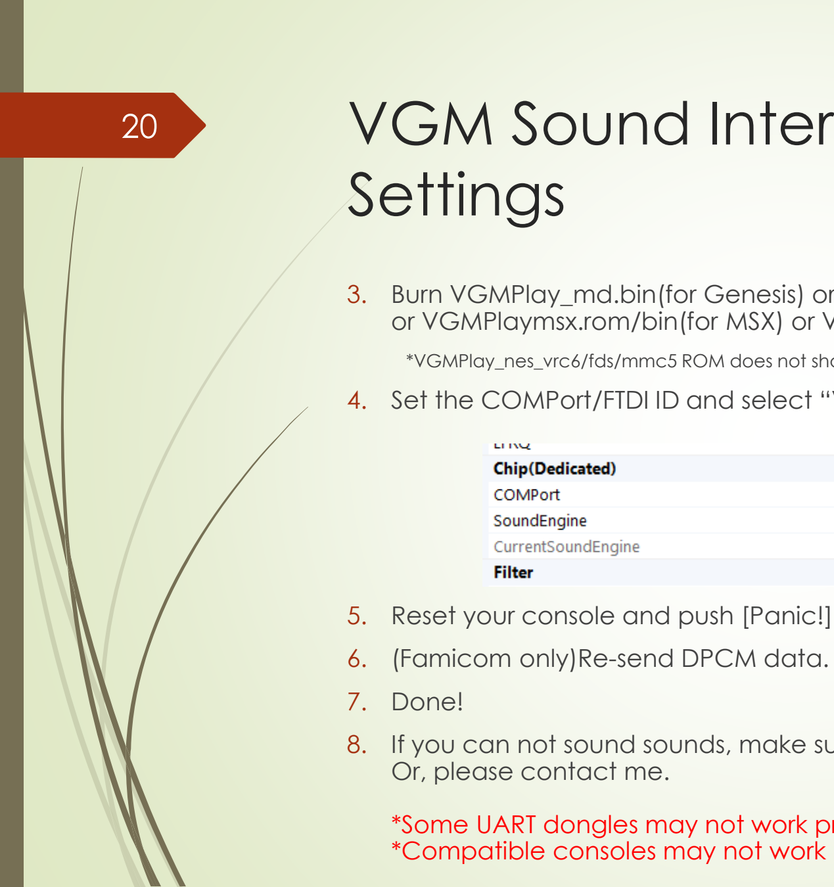
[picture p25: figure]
Settings; 6. (Famicom only)Re-send DPCM data.; 7. Done!; Or, please contact me.

# VGM Sound Interface(VSIF)

3. Burn VGMPlay_md.bin(for Genesis) or VGMPlay_sms.sms(for SMS) or VGMPlay_nes*.* (for Famicom) or VGMPlaymsx.rom/bin(for MSX) or VGMPlay_c64.prg to your FLASH Cart and so on.

*VGMPlay_nes_vrc6/fds/mmc5 ROM does not show any screen but same UI with VGMPlay_nes.nes UI
4. Set the COMPort/FTDI ID and select “VSIF ***” you wish.
5. Reset your console and push [Panic!] button
8. If you can not sound sounds, make sure soldering and COMPort name.

*Some UART dongles may not work properly.
*Compatible consoles may not work properly.

# VGM Sound Interface(VSIF) for Famicom spec

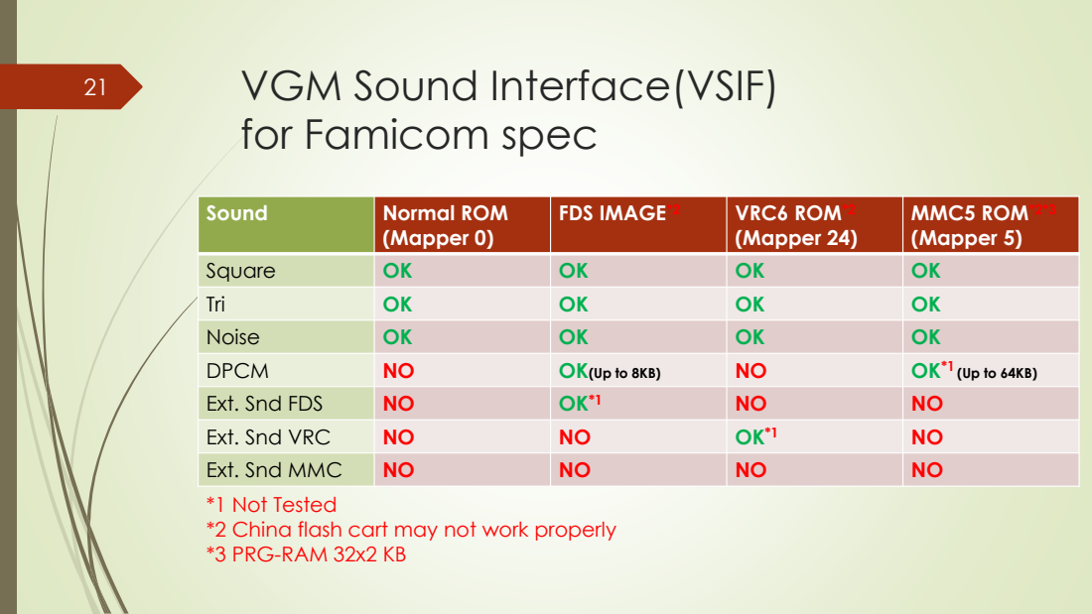
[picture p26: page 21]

Sound | Normal ROM (Mapper 0) | FDS IMAGE*2 | VRC6 ROM*2 (Mapper 24) | MMC5 ROM*2*3 (Mapper 5)

Square | OK | OK | OK | OK
Tri | OK | OK | OK | OK
Noise | OK | OK | OK | OK

DPCM | NO | OK(Up to 8KB) | NO | OK*1 (Up to 64KB)
Ext. Snd FDS | NO | OK*1 | NO | NO
Ext. Snd VRC | NO | NO | OK*1 | NO
Ext. Snd MMC | NO | NO | NO | NO

*1 Not Tested
*2 China flash cart may not work properly
*3 PRG-RAM 32x2 KB

22 | VGMPlayer

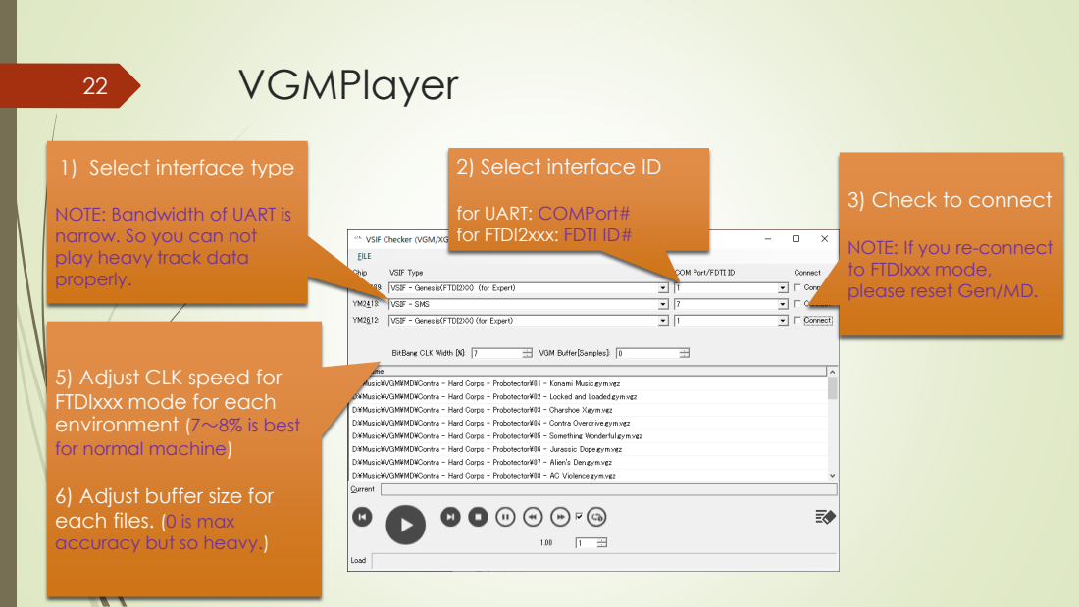
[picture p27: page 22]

1) Select interface type

2) Select interface ID

3) Check to connect

NOTE: Bandwidth of UART is
narrow. So you can not
play heavy track data
properly.

for UART: COMPort#
for FTDI2xxx: FDTI ID#

NOTE: If you re-connect
to FTDIxxx mode,
please reset Gen/MD.

5) Adjust CLK speed for
FTDIxxx mode for each
environment (7～8% is best
for normal machine)

6) Adjust buffer size for
each files. (0 is max
accuracy but so heavy.)

# Use CMI8738(OPL) Board *NO WARRANTY*

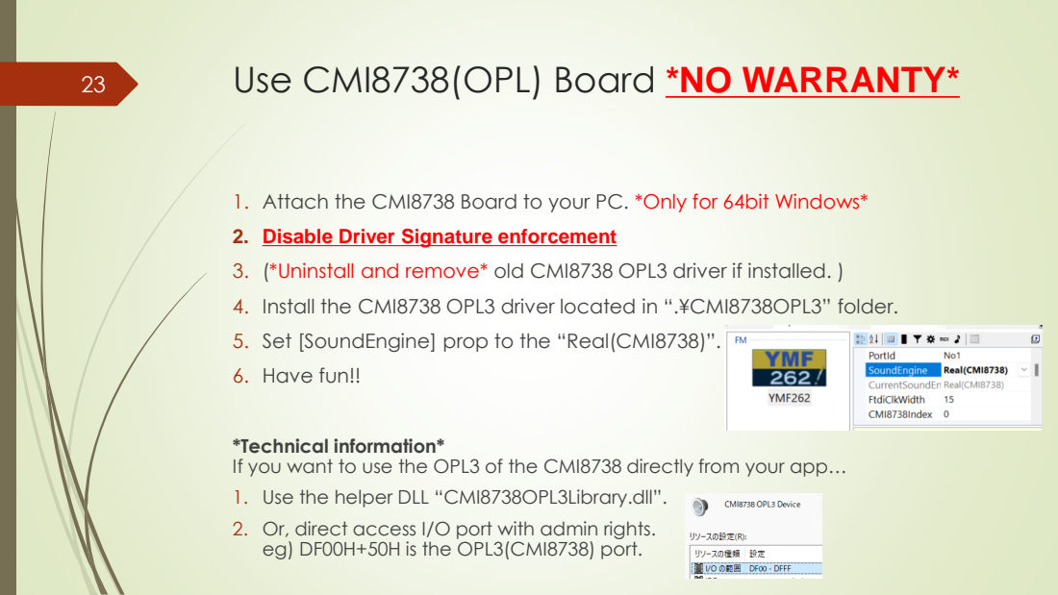
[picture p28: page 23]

1. Attach the CMI8738 Board to your PC. *Only for 64bit Windows*
2. Disable Driver Signature enforcement (https://docs.microsoft.com/windows-hardware/drivers/install/the-testsigning-boot-configuration-option)
3. (*Uninstall and remove* old CMI8738 OPL3 driver if installed. )
4. Install the CMI8738 OPL3 driver located in “.¥CMI8738OPL3” folder.
5. Set [SoundEngine] prop to the “Real(CMI8738)”.
6. Have fun!!

*Technical information*
If you want to use the OPL3 of the CMI8738 directly from your app…
1. Use the helper DLL “CMI8738OPL3Library.dll”.
2. Or, direct access I/O port with admin rights.
eg) DF00H+50H is the OPL3(CMI8738) port.

# Trouble Shooting for MAmi

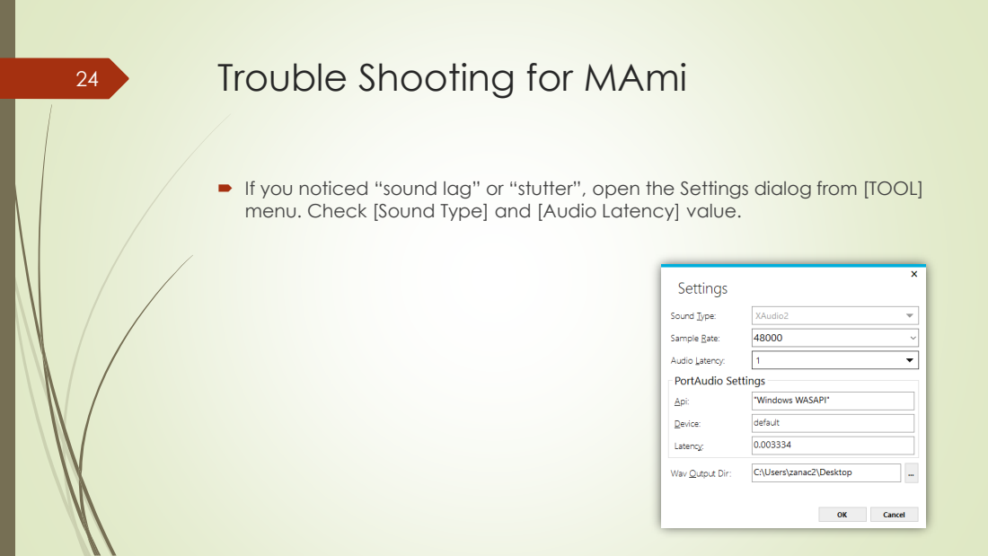
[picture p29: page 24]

If you noticed “sound lag” or “stutter”, open the Settings dialog from [TOOL]
menu. Check [Sound Type] and [Audio Latency] value.

25 | MIDI Implementation Chart 1

*Depends on the chip

Function | Transmitted | Recognize | Remarks
Basic Channel | - | 1-16: Defaut 1-16: Changed

Note Number* | - | 0-127
Velocity* | - | Yes: Note ON No: Note OFF

After Touch | - | No
Pitch Bend* | - | Yes | 8192: Default
Program Change | - | 0-127 | 0: Default

26 | MIDI Implementation Chart 2

*Depends on the chip

Function | Transmitted | Recognize | Remarks
Control Change 1 | - | Modulation | 0: OFF, 64: ON

5 | | Portamento Time | 0: Default
6 38 | | Data Entry MSB Data Entry LSB

7 | | Volume* | 127: Default
10 | | Panpot* | 64: Default 0: Left, 127: Right

11 | | Expression* | 127: Default
16-19 | | GPCS1 | Modify params
64 | | Hold 1 | 0: OFF, 64: ON
65 | | Portamento | 0: OFF, 64: ON

27 | MIDI Implementation Chart 3

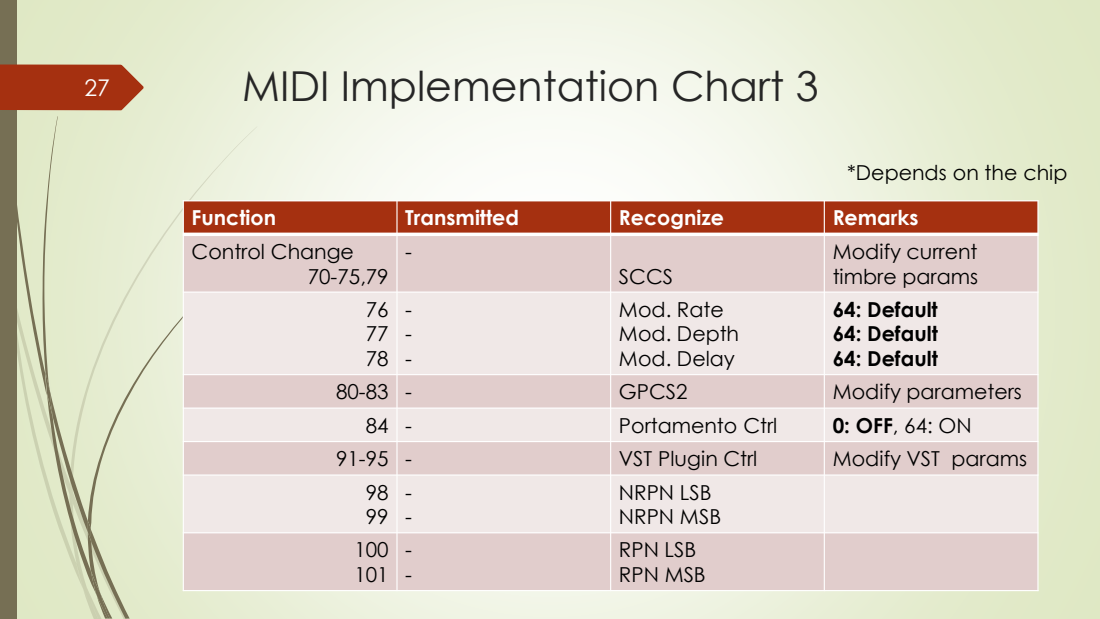
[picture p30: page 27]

*Depends on the chip

Function | Transmitted | Recognize | Remarks
Control Change 70-75,79 | - | SCCS | Modify current timbre params

76 77 78 | --- | Mod. Rate Mod. Depth Mod. Delay | 64: Default 64: Default 64: Default

80-83 | - | GPCS2 | Modify parameters
84 | - | Portamento Ctrl | 0: OFF, 64: ON
91-95 | - | VST Plugin Ctrl | Modify VST params
98 99 | -- | NRPN LSB NRPN MSB

100 101 | -- | RPN LSB RPN MSB

28 | MIDI Implementation Chart 4

*Depends on the chip

Function | Transmitted | Recognize | Remarks
Control Change 121 | - | Reset All Ctrl

126 | - | Mono Mode | 0: OFF 1-127: Max Voice Num.*

127 | - | Poly Mode | 0: OFF 1-127: Reserve Voice Num.* *Reset Mono Mode when set

29 | MIDI Implementation Chart 5

Function | MSB | LSB | Remarks
RPN | 0 | 0 | Pitch Bend Range 0-2-127 [Half Note]

0 | 5 | Mod Depth 0-127 [Relative]

30 | MIDI Implementation Chart 6

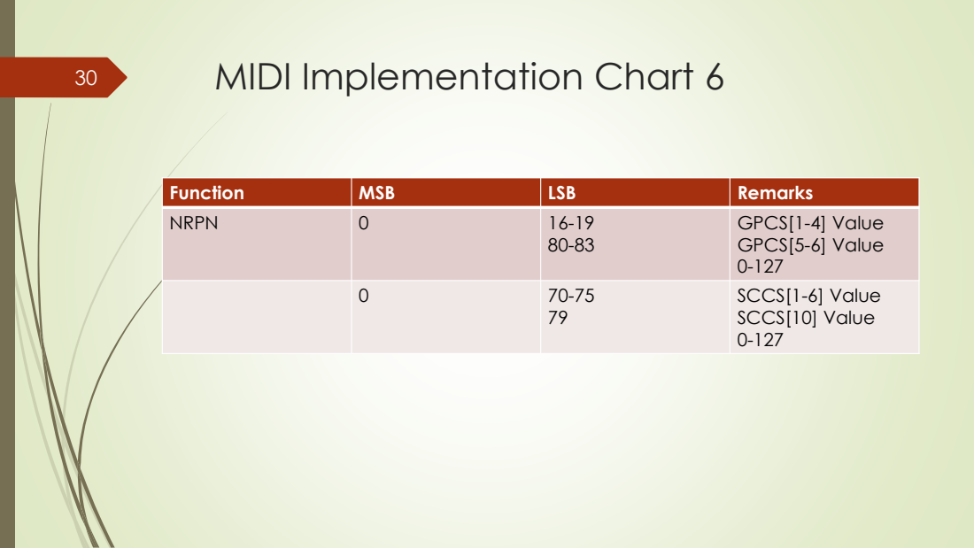
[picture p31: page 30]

Function | MSB | LSB | Remarks
NRPN | 0 | 16-19 80-83 | GPCS[1-4] Value GPCS[5-6] Value 0-127

0 | 70-75 79 | SCCS[1-6] Value SCCS[10] Value 0-127

31 | MIDI Implementation Chart 7

NRPN LSB Bx 62 <Device ID> ... Specify Device ID of existing instrument.
DATA LSB Bx 06 <Receiving MIDI ch(1-7) bit sets. 1=On, 0=Off>

NRPN MSB Bx 63 42 ... for MIDI ch(8-14)
DATA LSB Bx 06 <Receiving MIDI ch(8-14) bit sets. 1=On, 0=Off>

NRPN MSB Bx 63 43 ... for MIDI ch(15-16)
DATA LSB Bx 06 <Receiving MIDI ch(15-16) bit sets. 1=On, 0=Off>

bit 6 5 4 3 2 1 0

# VSIF – Generic (UART 115K), SMS(UART 115K) SPECIFICATION for AY-3-8910, YM2413

Baud rate: 115,200 bps
Protocol: 8 bits, None parity bit, 1 stop bit
1 packet : 2 bytes

# VSIF – MSX(FTDI) SPECIFICATION

# for AY-3-8910, YM2413, SCC-I, YMF262

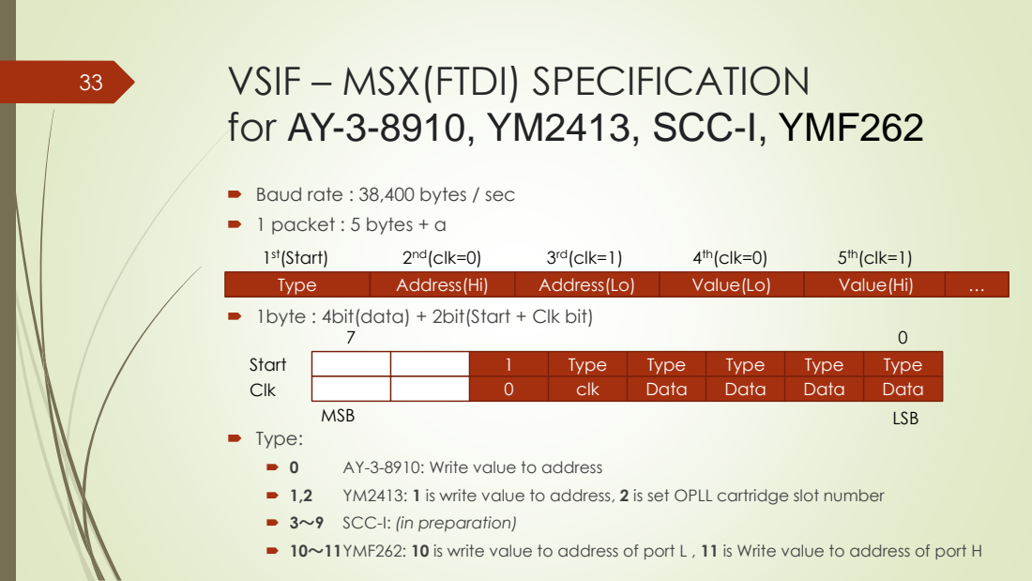
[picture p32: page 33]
Type:; AY-3-8910: Write value to address; YM2413: 1 is write value to address, 2 is set OPLL cartridge slot number; SCC-I: (in preparation); Type; Address(Hi); Address(Lo); Value(Lo); Value(Hi); st(Start); nd(clk=0); rd(clk=1); th(clk=0); th(clk=1); LSB; MSB; Start; Clk

Baud rate : 38,400 bytes / sec
1 packet : 5 bytes + α

1byte : 4bit(data) + 2bit(Start + Clk bit)

1 | Type | Type | Type | Type | Type
0 | clk | Data | Data | Data | Data

10～11YMF262: 10 is write value to address of port L , 11 is Write value to address of port H

# VSIF – C64(FTDI) SPECIFICATION for SID

Baud rate : 31,250 bytes / sec
1 packet : 6 bytes(1 byte value) or 9 bytes (2 bytes value) mode

1byte : 3bit(data) + 2bit(Start(Active low) + Clk(Active low) bit)

9 bytes mode flag:

th byte data

NOTE: In 9bytes mode, send value
for Address+1 data first, second is
Address+0 data

# Integrate with MAmidiMEmo via RPC

- MAmidiMEmo will starts RPC server on port 30000 at startup.
So, your application can be integrate with the MAmidiMEmo via RPC. MAmidiMEmo provides the following API

//Write the value to the address to the specific chip
void DirectAccessToChip(unsigned char DeviceID, unsigned char UnitNo, unsigned int address, unsigned int data)

* You can confirm the DeviceID and UnitNumber from the property.
* Currently, OPLL(ID9), SCC(ID7), AY8910(ID11) chips are supported.
* If you want to use SCC1(aka SCC+), you need to add 0x100 to the address.
- Ex)

35

rpc::client* m_rpcClient = new rpc::client("localhost", 30000); //Open RPC port
:::
//Write SCC1 wave form
m_rpcClient->async_call("DirectAccessToChip", (unsigned char)7, (unsigned char)0, (unsigned int)0x100, (unsigned int)10); //All sound off for AY8910
m_rpcClient->async_call("DirectAccessToChip", (unsigned char)11, (unsigned char)0, (unsigned int)7, (unsigned int)0x3f); //Key off 1ch for OPLL
m_rpcClient->async_call("DirectAccessToChip", (unsigned char)9, (unsigned char)0, (unsigned int)0x20, (unsigned int)0x0); :::
m_rpcClient->~client(); //Close RPC port

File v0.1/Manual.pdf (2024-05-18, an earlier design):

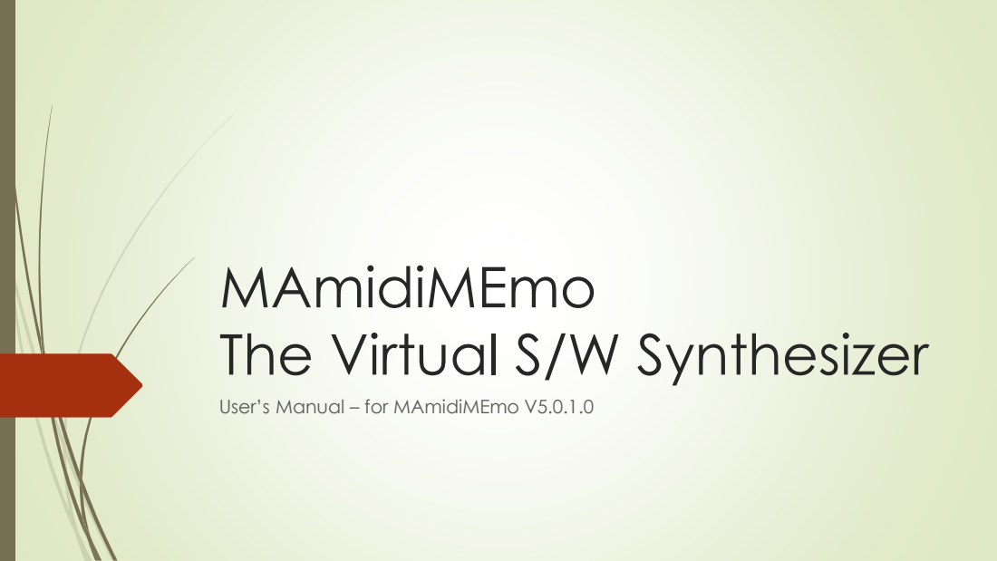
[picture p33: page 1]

MAmidiMEmo
The Virtual S/W Synthesizer

User’s Manual – for MAmidiMEmo V5.0.1.0

# What is the MAmidiMEmo?

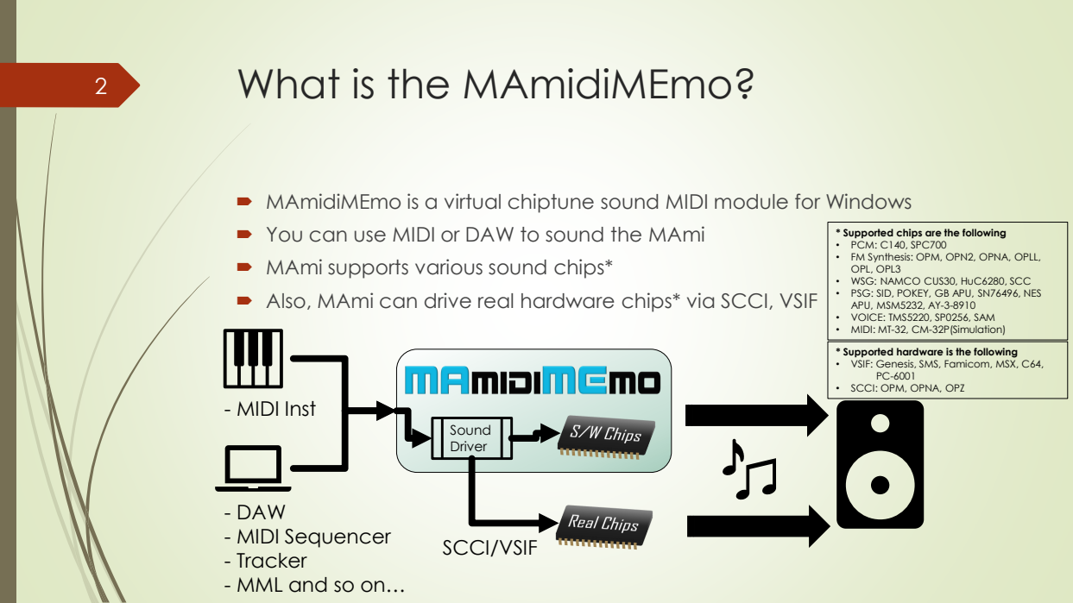
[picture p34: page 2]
- MIDI Inst; Sound Driver; SCCI/VSIF

MAmidiMEmo is a virtual chiptune sound MIDI module for Windows
You can use MIDI or DAW to sound the MAmi
MAmi supports various sound chips*
Also, MAmi can drive real hardware chips* via SCCI, VSIF

* Supported chips are the following
• PCM: C140, SPC700
• FM Synthesis: OPM, OPN2, OPNA, OPLL,
OPL, OPL3
• WSG: NAMCO CUS30, HuC6280, SCC
• PSG: SID, POKEY, GB APU, SN76496, NES
APU, MSM5232, AY-3-8910
• VOICE: TMS5220, SP0256, SAM
• MIDI: MT-32, CM-32P(Simulation)

* Supported hardware is the following
• VSIF: Genesis, SMS, Famicom, MSX, C64,

• SCCI: OPM, OPNA, OPZ

- DAW
- MIDI Sequencer
- Tracker
- MML and so on…

# Install & Basic Settings

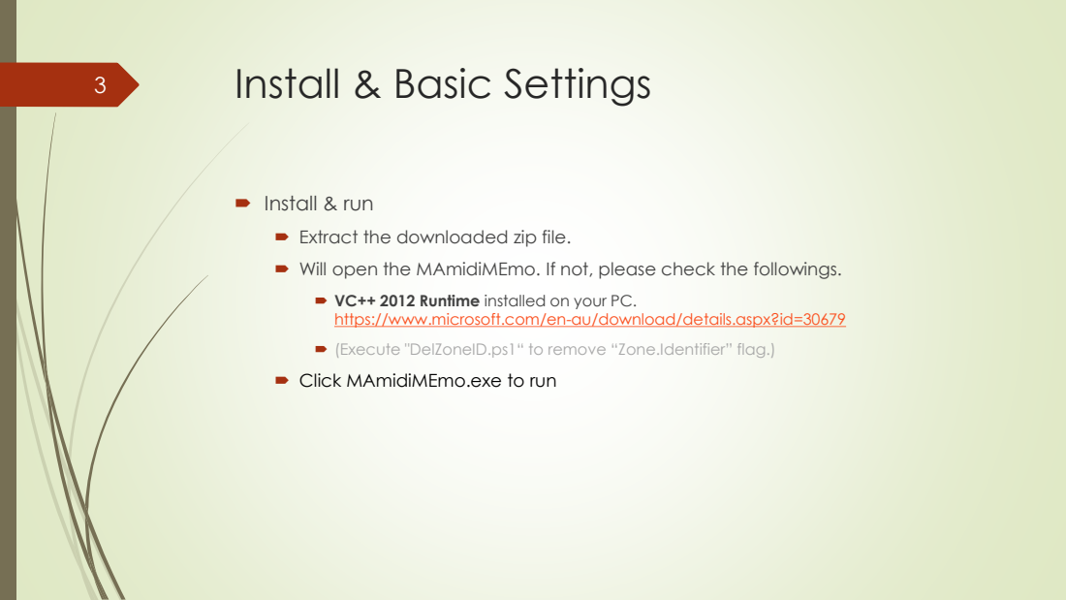
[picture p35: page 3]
Install & run

Extract the downloaded zip file.
Will open the MAmidiMEmo. If not, please check the followings.

VC++ 2012 Runtime installed on your PC.
https://www.microsoft.com/en-au/download/details.aspx?id=30679

(Execute "DelZoneID.ps1“ to remove “Zone.Identifier” flag.)
Click MAmidiMEmo.exe to run

# Window Overview

# Add and Remove a Chip

To add
Select the chip
from this menu.

# Edit chip and sound parameters

7 | Edit FM registers with a GUI editor

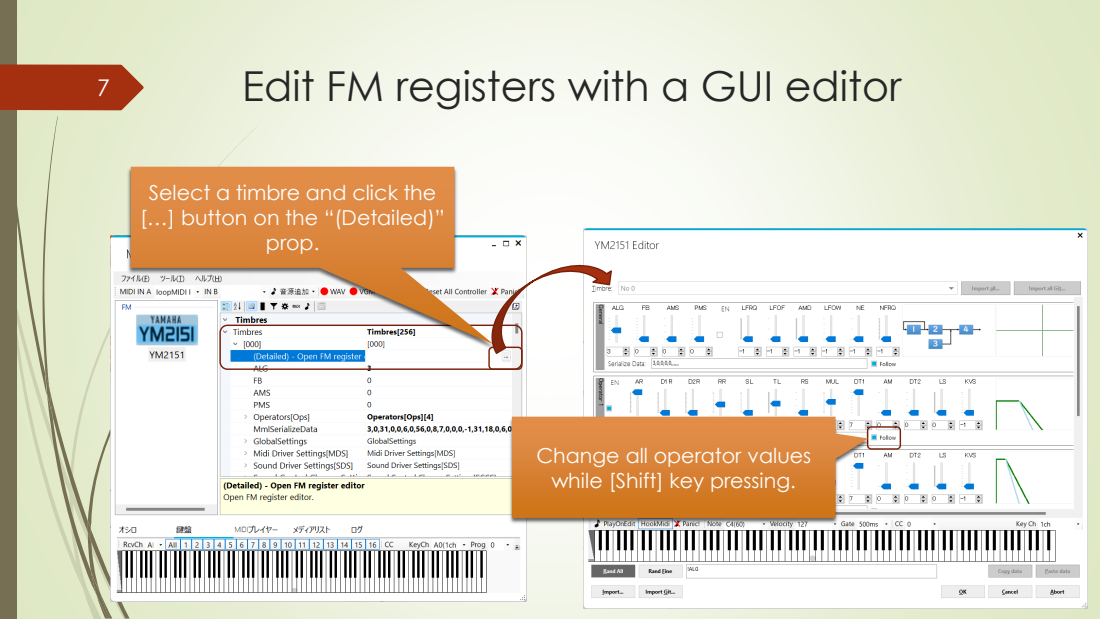
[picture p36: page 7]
prop.

Select a timbre and click the
[…] button on the “(Detailed)”

Change all operator values
while [Shift] key pressing.

Between MIDI ch and Chip ch Relation.

You don’t need to concern the Chip ch. , generally.
MAmidiMEmo will assign suitable Chip ch. automatically.
However, you need to concern a max ch. number of the Chip.
MAmidiMEmo will assign oldest sounding ch. to sound the new sounds.

MAmidiMemo will assign
empty ch. or oldest
sounsing ch. , generally.

# Sounding Structure

MAmidiMEmo outputs a sound from MIDI message along with the following
structure.
So, at least, you need to edit the Timbre parameters to sound something.

# Timbre

Generally, a chip has 256 Timbres, 256 CombinedTimbres, 128 DrumTimbres.
CombinedTimbre can sound multiple Timbers at the same time (up to 4)
DrumTimbre can sound Timbes as a Drum sounds (Ignoring Note Off msg).
You can change the Timbre parameters on the Chip Parameter Editor.
Generally, you need to learn the chip specification to edit the chip
parameters.

# Timbre Structure

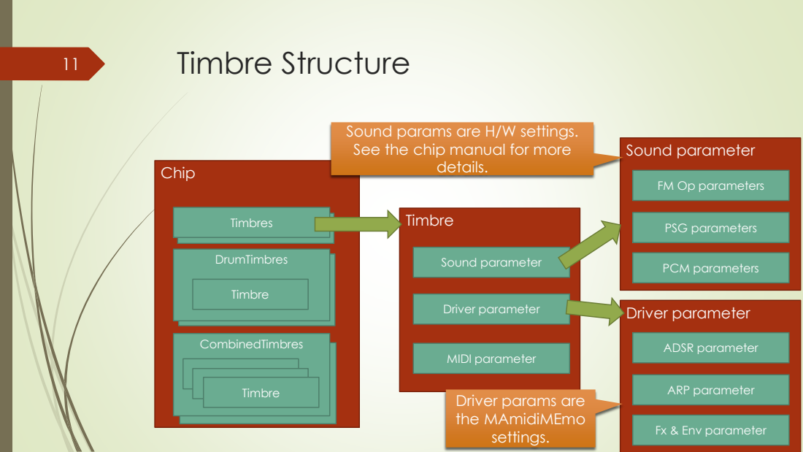
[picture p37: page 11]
Chip; CombinedTimbre; Timbre Timbre; Timbre Timbres; DrumTimbre; Timbre; DrumTimbres; CombinedTimbres; Sound parameter; Driver parameter; MIDI parameter; PSG parameters; PCM parameters; ADSR parameter; ARP parameter; details.

Sound params are H/W settings.
See the chip manual for more

FM Op parameters

Timbre

Driver params are
the MAmidiMEmo
settings.

Fx & Env parameter

# Driver parameters - Fx & Env Structure

You can make for a rich sound by using driver params.
Especially, FxS can do it.

Fx & Env parameter

Click here to open
the GUI Editor.

# Sample sounds

There are sample sound files in the “Samples” folder. You can drop a
sample file “*.MAmi" to the left pane.

# Additional files

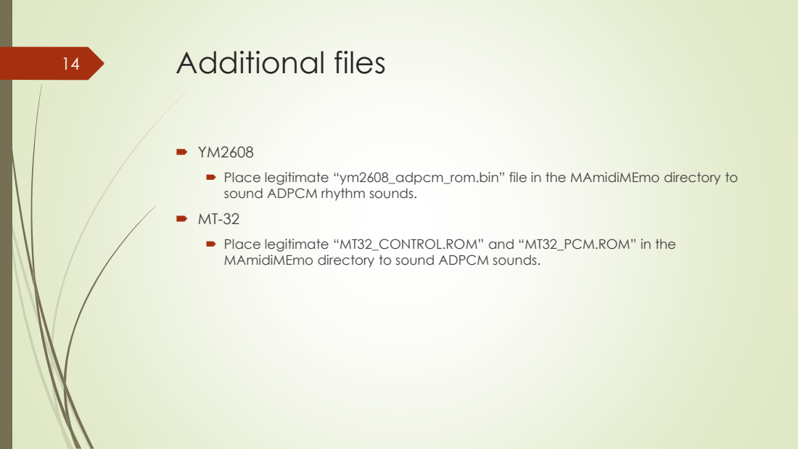
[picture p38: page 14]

Place legitimate “ym2608_adpcm_rom.bin” file in the MAmidiMEmo directory to
sound ADPCM rhythm sounds.

Place legitimate “MT32_CONTROL.ROM” and “MT32_PCM.ROM” in the
MAmidiMEmo directory to sound ADPCM sounds.

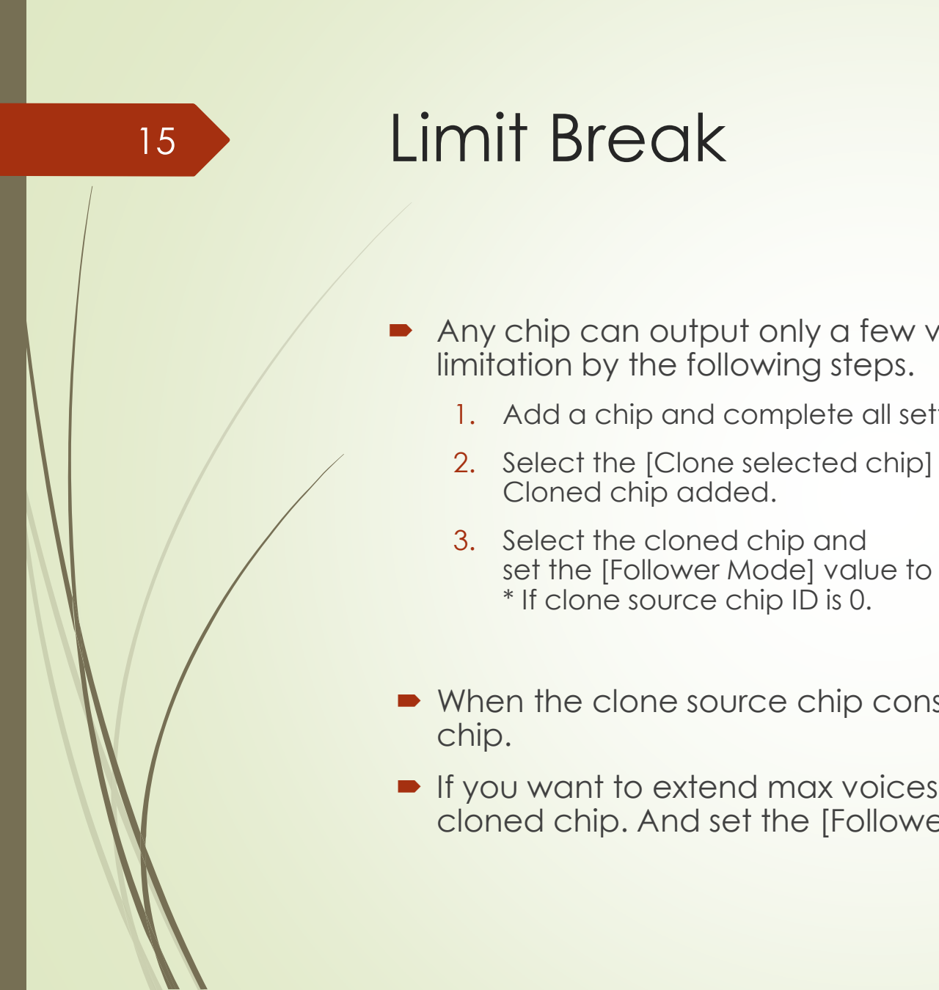
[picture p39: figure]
Limit Break; limitation by the following steps.; 2. Select the [Clone selected chip] Cloned chip added.; 3. Select the cloned chip and; * If clone source chip ID is 0.; chip.

- Any chip can output only a few voices. However, MAmidiMEmo can break this
1. Add a chip and complete all settings the chip.

set the [Follower Mode] value to “Unit0*”.

- When the clone source chip consumed all voices, the cloned chip sound for the
- If you want to extend max voices more, select the [Clone selected chip] of the cloned chip. And set the [Follower Mode] value to “Unit0”.

Use a real hardware

You can use a real hardware by using the VSIF / PCI device.

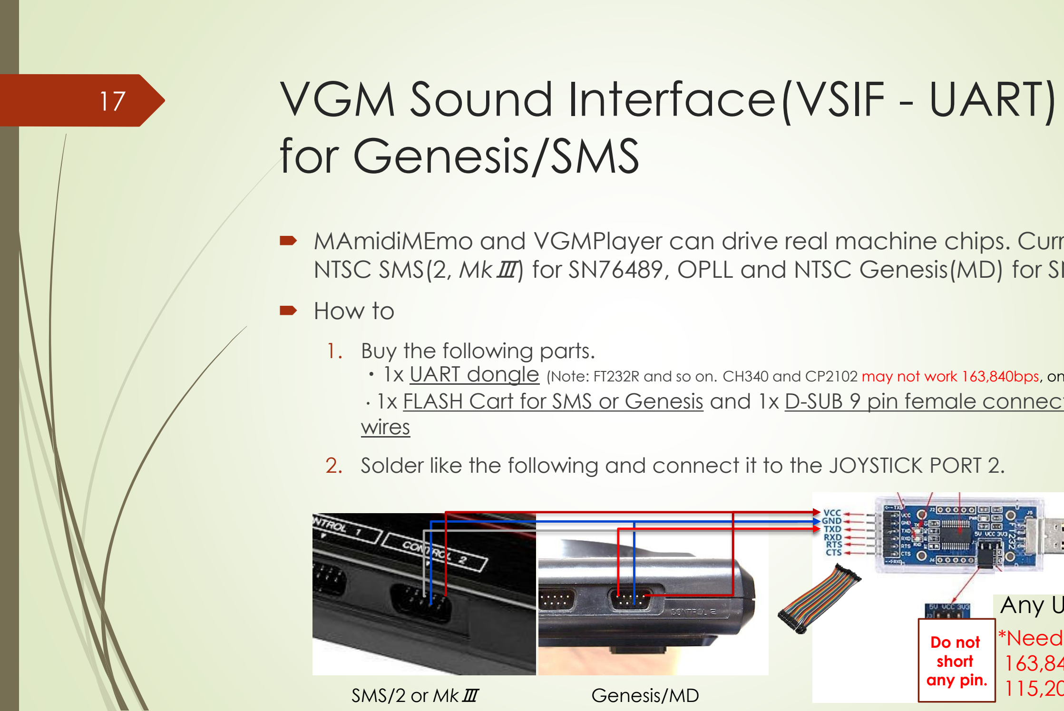
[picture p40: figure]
VGM Sound Interface(VSIF - UART) for Genesis/SMS; How to; 1. Buy the following parts.; wires; SMS/2 or MkⅢ; Genesis/MD; Do not short any pin.

- MAmidiMEmo and VGMPlayer can drive real machine chips. Currently supports NTSC SMS(2, MkⅢ) for SN76489, OPLL and NTSC Genesis(MD) for SN76489, OPN2.

・1x UART dongle (Note: FT232R and so on. CH340 and CP2102 may not work 163,840bps, only 115,200bps.)
・1x FLASH Cart for SMS or Genesis and 1x D-SUB 9 pin female connector and DuPont
2. Solder like the following and connect it to the JOYSTICK PORT 2.

*Need to support 163,840bps for MD 115,200bps for MD, SMS; Any UART dongle

# VGM Sound Interface(VSIF - FTDI)

- MAmidiMEmo and VGMPlayer can drive real machine chips more faster if you use FTDI2xx(232R, 232H and so on). Currently supports NTSC Genesis(MD) for

・1x FTDI2XX dongle (FT232R or FT2232H and so on. Need to support 5V. *WARN* Please use a genuine dongle.) (https://www.voltlog.com/tag/ft232-a50285bi/)
・1x FLASH Cart for Genesis and 1x D-SUB 9 pin female connector and DuPont wires

Any FTDI2XX dongle DTR DSR DCD; Do not short any pin.

2. Solder like the following and connect it to the JOYSTICK PORT 2.

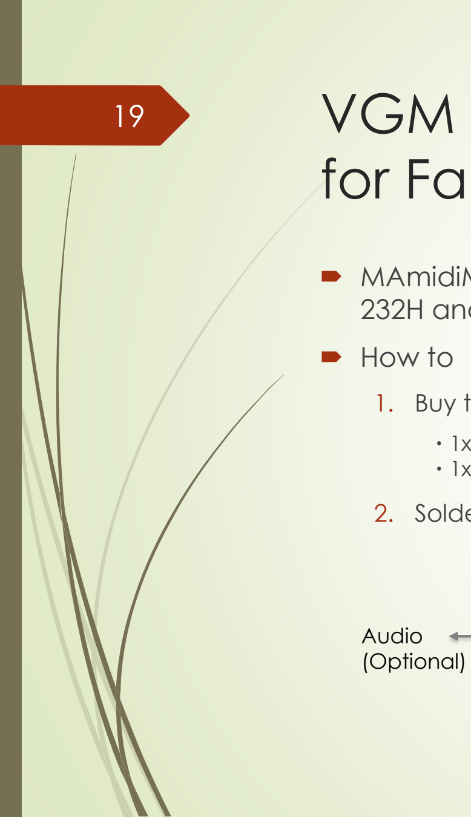
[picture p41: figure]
How to; Audio (Optional)

# VGM Sound Interface(VSIF - FTDI) for Famicom

- MAmidiMEmo can drive real machine chips more faster if you use FTDI2xx(232R, 232H and so on). Currently supports NTSC Famicom and RP2A03(No DAC)/FDS/VRC6.
1. Buy the following parts.

・1x FTDI2XX dongle (FT232R and so on. Need to support 5V. *WARN* Please use a genuine dongle.) (https://www.voltlog.com/tag/ft232-a50285bi/)
・1x FLASH Cart for Famicom and 1x D-SUB 15 pin female connector for FC and DuPont wires
2. Solder like the following.

Famicom; DTR; Any FTDI2XX dongle; Do not short any pin.

# VGM Sound Interface(VSIF - FTDI) for MSX/PC-6001

- MAmidiMEmo can drive real chips on MSX/P6 if you use FTDI2xx(232R, 232H and so on). Currently supports NTSC MSX for AY-3-8910,OPLL,SCC+,OPM,OPNA,OPL3,Y8950. NOTE1: Be sure to select proper SLOT# for SCC to use SCC.
Set FTDI clk value to 25 for each chip on normal MSX. If you have a tR, you can decrease value. NOTE2: You can not use the VGM_P6M.ROM on 戦士のカートリッジ for PC-6001
- How to (You can also create a dedicated dongle from the Gerber file.) (https://github.com/110-kenichi/mame/tree/master/docs/MAmidiMEmo/MAmi-VSIF_MSX_PCB)
1. Buy the following parts.

・1x FTDI2XX dongle (FT232R and so on. Need to support 5V. *WARN* Please use a genuine dongle.) (https://www.voltlog.com/tag/ft232-a50285bi/)
・1x D-SUB 9 pin female connector and DuPont wires
2. Solder like the following and connect it to the JOYSTICK P2(MSX), P1(P6).

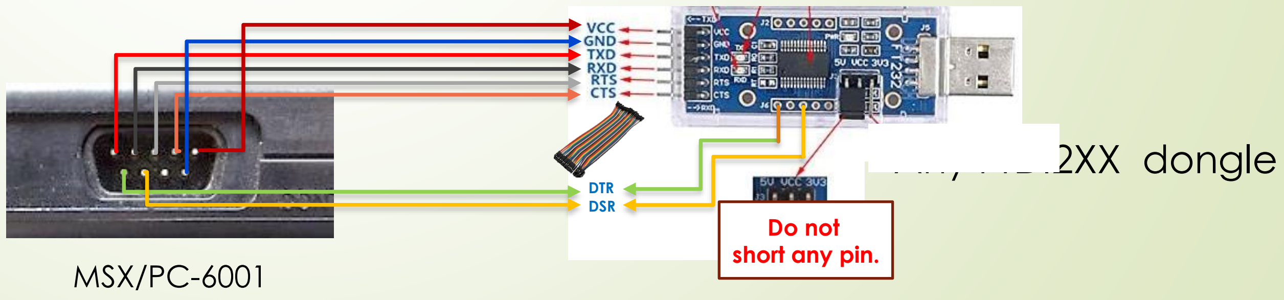
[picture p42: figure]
MSX/PC-6001; Any FTDI2XX dongle; DTR DSR; Do not short any pin.

# VGM Sound Interface(VSIF - FTDI) for Commodore 64(C64)

- MAmidiMEmo can drive real MSX machine chips if you use FTDI2xx(232R, 232H and so on). Currently supports NTSC/PAL C64 for SIDs.
I recommend to use ARMSID with ADSR bud fixing.
1. Buy the following parts.

・1x FTDI2XX dongle (FT232R and so on. Need to support 5V. *WARN* Please usea genuine dongle.) (https://www.voltlog.com/tag/ft232-a50285bi/)
・1x D-SUB 9 pin female connector and DuPont wires

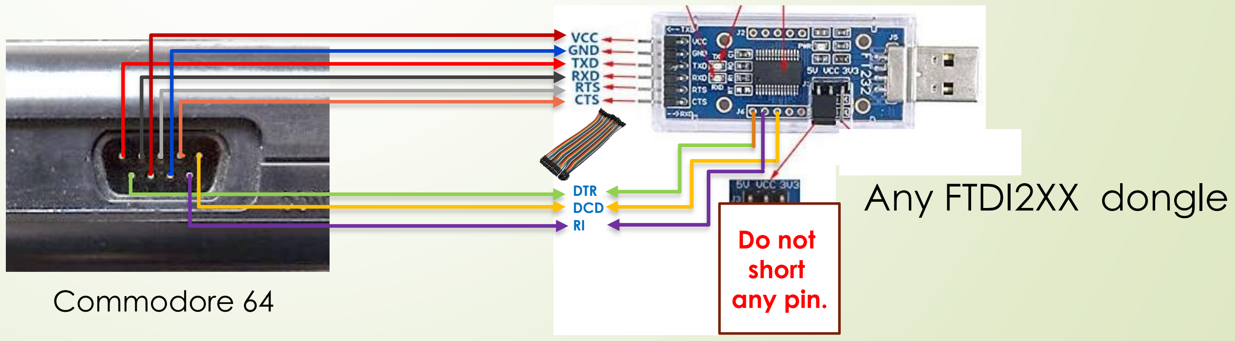
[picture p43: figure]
Commodore 64; Any FTDI2XX dongle DTR DCD RI; Do not short any pin.

2. Solder like the following and connect it to the JOYSTICK PORT 2.

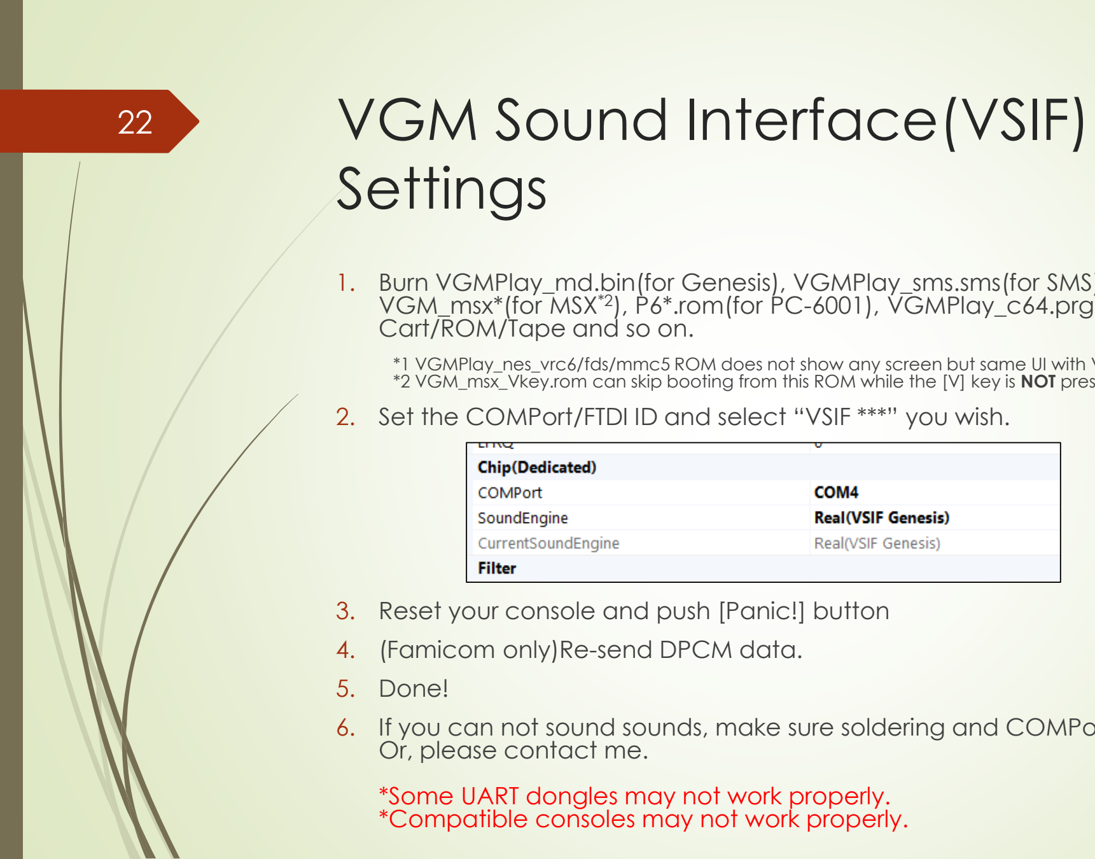
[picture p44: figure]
VGM Sound Interface(VSIF) Settings; Cart/ROM/Tape and so on.; 4. (Famicom only)Re-send DPCM data.; 5. Done!; Or, please contact me.

1. Burn VGMPlay_md.bin(for Genesis), VGMPlay_sms.sms(for SMS), VGMPlay_nes*.* (for Famicom*1), VGM_msx*(for MSX*2), P6*.rom(for PC-6001), VGMPlay_c64.prg(for V64) to your FLASH

*1 VGMPlay_nes_vrc6/fds/mmc5 ROM does not show any screen but same UI with VGMPlay_nes.nes UI
*2 VGM_msx_Vkey.rom can skip booting from this ROM while the [V] key is NOT pressed at boot time.
2. Set the COMPort/FTDI ID and select “VSIF ***” you wish.
3. Reset your console and push [Panic!] button
6. If you can not sound sounds, make sure soldering and COMPort name.

*Some UART dongles may not work properly.
*Compatible consoles may not work properly.

# VGM Sound Interface(VSIF) for Famicom spec

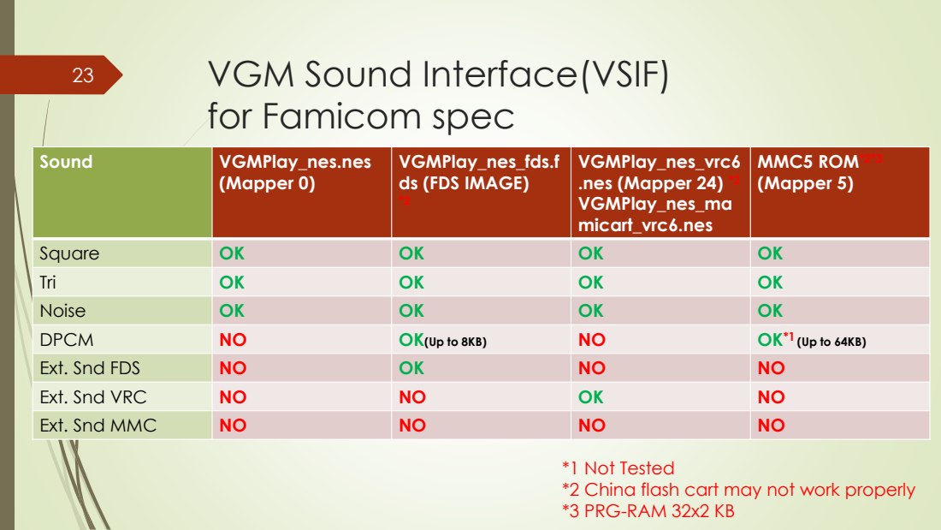
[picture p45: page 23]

Sound | VGMPlay_nes.nes (Mapper 0) | VGMPlay_nes_fds.f ds (FDS IMAGE) *2 | VGMPlay_nes_vrc6 .nes (Mapper 24) *2 VGMPlay_nes_ma micart_vrc6.nes | MMC5 ROM*2*3 (Mapper 5)

Square | OK | OK | OK | OK
Tri | OK | OK | OK | OK
Noise | OK | OK | OK | OK

DPCM | NO | OK(Up to 8KB) | NO | OK*1 (Up to 64KB)
Ext. Snd FDS | NO | OK | NO | NO
Ext. Snd VRC | NO | NO | OK | NO
Ext. Snd MMC | NO | NO | NO | NO

*1 Not Tested
*2 China flash cart may not work properly
*3 PRG-RAM 32x2 KB

# MEMO: FTDI UART NAME <-> Bit Number

# Use CMI8738(OPL3) PCI Board

# *Please use at your own risk*

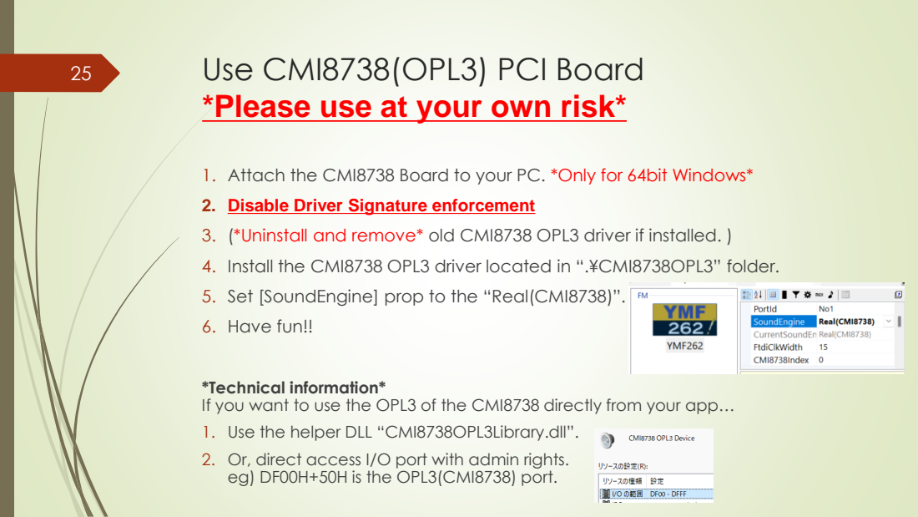
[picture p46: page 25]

1. Attach the CMI8738 Board to your PC. *Only for 64bit Windows*
2. Disable Driver Signature enforcement (https://docs.microsoft.com/windows-hardware/drivers/install/the-testsigning-boot-configuration-option)
3. (*Uninstall and remove* old CMI8738 OPL3 driver if installed. )
4. Install the CMI8738 OPL3 driver located in “.¥CMI8738OPL3” folder.
5. Set [SoundEngine] prop to the “Real(CMI8738)”.
6. Have fun!!

*Technical information*
If you want to use the OPL3 of the CMI8738 directly from your app…
1. Use the helper DLL “CMI8738OPL3Library.dll”.
2. Or, direct access I/O port with admin rights.
eg) DF00H+50H is the OPL3(CMI8738) port.

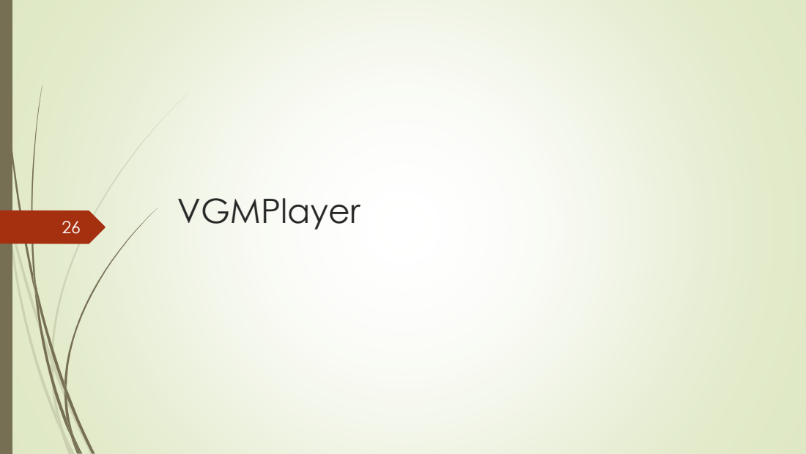
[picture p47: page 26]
VGMPlayer 26

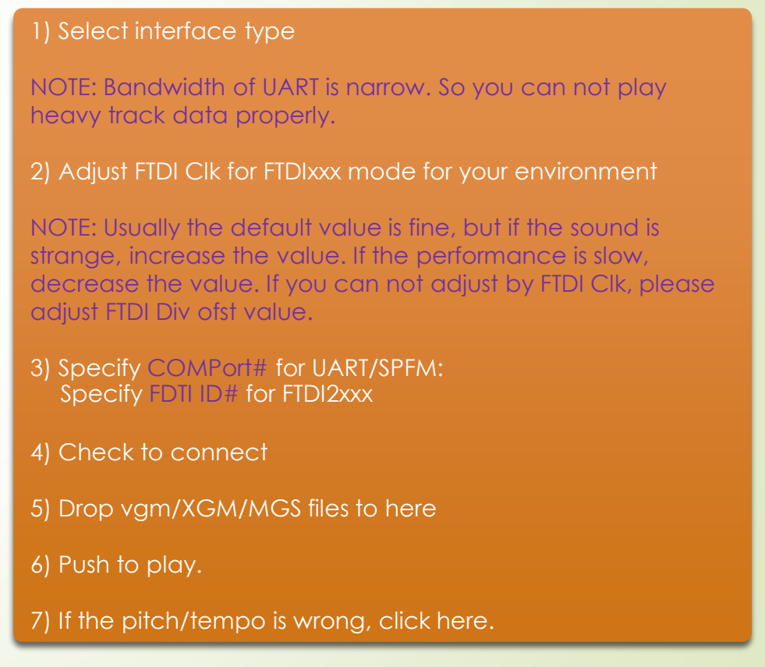
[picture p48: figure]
1) Select interface type; heavy track data properly.; adjust FTDI Div ofst value.; 3) Specify COMPort# for UART/SPFM: Specify FDTI ID# for FTDI2xxx; 4) Check to connect; 5) Drop vgm/XGM/MGS files to here; 6) Push to play.

NOTE: Bandwidth of UART is narrow. So you can not play

2) Adjust FTDI Clk for FTDIxxx mode for your environment

NOTE: Usually the default value is fine, but if the sound is strange, increase the value. If the performance is slow, decrease the value. If you can not adjust by FTDI Clk, please

7) If the pitch/tempo is wrong, click here.

VGMPlayer can play a vgm/xgm/mgs file on a real chip via VSIF or SPFM. Substitutes for similar chips are also available. For example, an OPL track can be played on an OPL3 chip.

Known issues and limitations 28

# Known issues and limitations


1. MT-32 & CM32-P can not store/restore last settings.
2. HuC6820 suddenly stop sounding. Please restart MAmi.
3. MAmidiMEmo process stuck after sound interface changed if you used
SCCI interface.
4. You need to save the data manually on the DAW (Cubase and so on).
Or, keep open the dummy editor window of the MAmidiMemo.

# Trouble Shooting for MAmi

If you noticed “sound lag” or “stutter”, open the Settings dialog from [TOOL]
menu. Check [Sound Type] and [Audio Latency] value.

32 | MIDI Implementation Chart 1

*Depends on the chip

Function | Transmitted | Recognize | Remarks
Basic Channel | - | 1-16: Defaut 1-16: Changed

Note Number* | - | 0-127
Velocity* | - | Yes: Note ON No: Note OFF

After Touch | - | No
Pitch Bend* | - | Yes | 8192: Default
Program Change | - | 0-127 | 0: Default

33 | MIDI Implementation Chart 2


*Depends on the chip

Function | Transmitted | Recognize | Remarks
Control Change 1 | - | Modulation | 0: OFF, 64: ON

5 | | Portamento Time | 0: Default
6 38 | | Data Entry MSB Data Entry LSB

7 | | Volume* | 127: Default
10 | | Panpot* | 64: Default 0: Left, 127: Right

11 | | Expression* | 127: Default
16-19 | | GPCS1 | Modify params

34 | MIDI Implementation Chart 3

*MONO and RecentlyUsedSlot mode only

Function | Transmitted | Recognize | Remarks
Control Change 64 | | Hold 1 | 0: OFF, 64: ON

65 | | Portamento | 0: OFF, 64: ON
68 | | Legato* | 0: OFF, 64: ON
70-75,79 | - | SCCS | Modify current timbre params

76 77 78 | --- | Mod. Rate Mod. Depth Mod. Delay | 64: Default 64: Default 64: Default

80-83 | - | GPCS2 | Modify parameters
84 | - | Portamento Ctrl | 0: OFF, 64: ON
91-95 | - | VST Plugin Ctrl | Modify VST params

35 | MIDI Implementation Chart 4

*Depends on the chip

Function | Transmitted | Recognize | Remarks
Control Change 98 99 | -- | NRPN LSB NRPN MSB | See after pages

100 101 | -- | RPN LSB RPN MSB | Sett after pages

121 | - | Reset All Ctrl
126 | - | Mono Mode | 0: OFF 1-127: Max Voice Num.*

127 | - | Poly Mode | 0: OFF 1-127: Reserve Voice Num.* *Reset Mono Mode when set

36 | MIDI Implementation Chart 5

Function | MSB | LSB | Remarks
RPN | 0 | 0 | Pitch Bend Range 0 ～ 2 ～ 127 [Half Note]

0 | 1 | Fine Tune[cent] -8193 ～ 0 ～ 8192 [-100 cent ～ 99.9 cent]

0 | 5 | Mod Depth 0 ～ 127 [Relative]

37 | MIDI Implementation Chart 6


Function | MSB | LSB | Remarks
NRPN | 0 | 16-19 80-83 | GPCS[1-4] Value GPCS[5-6] Value 0-127

0 | 70-75 79 | SCCS[1-6] Value SCCS[10] Value 0-127

38 | MIDI Implementation Chart 7

NRPN LSB Bx 62 <Device ID> ... Specify Device ID of existing instrument.
DATA LSB Bx 06 <Receiving MIDI ch(1-7) bit sets. 1=On, 0=Off>

NRPN MSB Bx 63 42 ... for MIDI ch(8-14)
DATA LSB Bx 06 <Receiving MIDI ch(8-14) bit sets. 1=On, 0=Off>

NRPN MSB Bx 63 43 ... for MIDI ch(15-16)
DATA LSB Bx 06 <Receiving MIDI ch(15-16) bit sets. 1=On, 0=Off>

bit 6 5 4 3 2 1 0

39 | MIDI Implementation Chart 8

0: Start Recording
1: Set Loop Start Point
2: Set Loop End Point
3: Stop Recording

NOTE: If you stop playing in the middle of a
performance, the recording will not stop. Please
press the XGM recording button manually.

# VSIF – Generic (UART 115K), SMS(UART 115K) SPECIFICATION for AY-3-8910, YM2413

Baud rate: 115,200 bps
Protocol: 8 bits, None parity bit, 1 stop bit
1 packet : 2 bytes

# VSIF – MSX/P6(FTDI) SPECIFICATION

## for AY-3-8910, OPLL, SCC-I, OPL3, OPM, OPNA/OPN2, OPN

Type:; AY-3-8910: Write value to address; YM2413: 1 is write value to address, 2 is set OPLL cartridge slot number; SCC-I: (in preparation); YMF262: 10 is write value to address of port L , 11 is Write value to address of port H; OPM: Write value to address; DCSG: Write value to address; OPNA/OPN2: Write value to address; OPN: Write value to address; Type; Address(Hi); Address(Lo); Value(Lo); Value(Hi); st(Start); nd(clk=0); rd(clk=1); th(clk=0); th(clk=1); LSB; MSB; Start; Clk

Baud rate : 38,400 bytes / sec
1 packet : 5 bytes + α

1byte : 4bit(data) + 2bit(Start + Clk bit)

1 | Type | Type | Type | Type | Type
0 | clk | Data | Data | Data | Data

# VSIF – C64(FTDI) SPECIFICATION for SID

Baud rate : 31,250 bytes / sec
1 packet : 6 bytes(1 byte value) or 9 bytes (2 bytes value) mode

1byte : 3bit(data) + 2bit(Start(Active low) + Clk(Active low) bit)

9 bytes mode flag:

th byte data

NOTE: In 9bytes mode, send value
for Address+1 data first, second is
Address+0 data

Integrate with MAmidiMEmo via RPC; option.; MAmidiMEmo provides the following API; try { //Check connection; } catch(...) { //Failed } ::: //Write SCC1 wave form; //All sound off for AY8910; //Key off 1ch for OPLL

- MAmidiMEmo will starts RPC server on port 30000 at startup with “-chip_server”

So, your application can be integrate with the MAmidiMEmo via RPC.

//Write the value to the address to the specific chip
void DirectAccessToChip(unsigned char DeviceID, unsigned char UnitNo, unsigned int address, unsigned int data)

* You can confirm the DeviceID and UnitNumber from the property.
* Currently, OPLL(ID9), SCC(ID7), AY8910(ID11), YM2608(ID23) chips are supported.
* If you want to use SCC1(aka SCC+), you need to add 0x100 to the address.

rpc::client* m_rpcClient = new rpc::client("localhost", 30000); //Open RPC port

m_rpcClient->call("DirectAccessToChip", (unsigned char)0, (unsigned char)0, (unsigned int)0, (unsigned int)0);

m_rpcClient->async_call("DirectAccessToChip", (unsigned char)7, (unsigned char)0, (unsigned int)0x100, (unsigned int)10);

m_rpcClient->async_call("DirectAccessToChip", (unsigned char)11, (unsigned char)0, (unsigned int)7, (unsigned int)0x3f);

m_rpcClient->async_call("DirectAccessToChip", (unsigned char)9, (unsigned char)0, (unsigned int)0x20, (unsigned int)0x0);

m_rpcClient->~client(); //Close RPC port(But, may not working properly. Recommend commenting out this line.)

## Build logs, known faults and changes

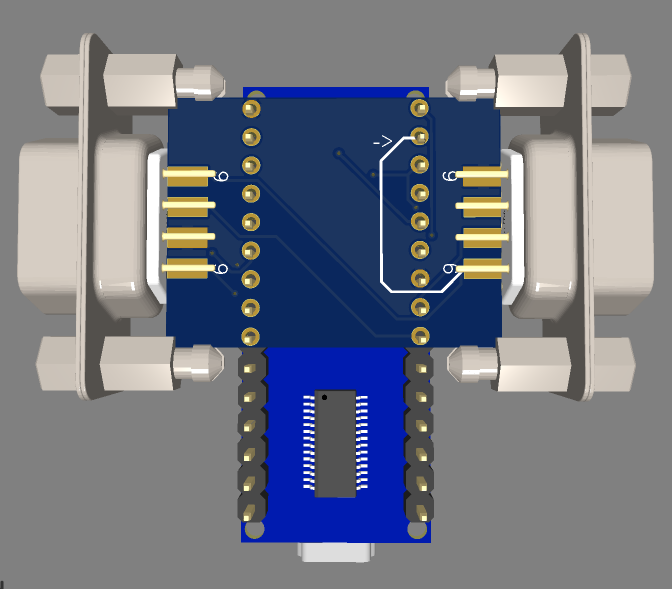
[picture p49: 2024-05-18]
v0.1 Fix.png

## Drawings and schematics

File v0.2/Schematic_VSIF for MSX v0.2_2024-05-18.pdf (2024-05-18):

## MSX

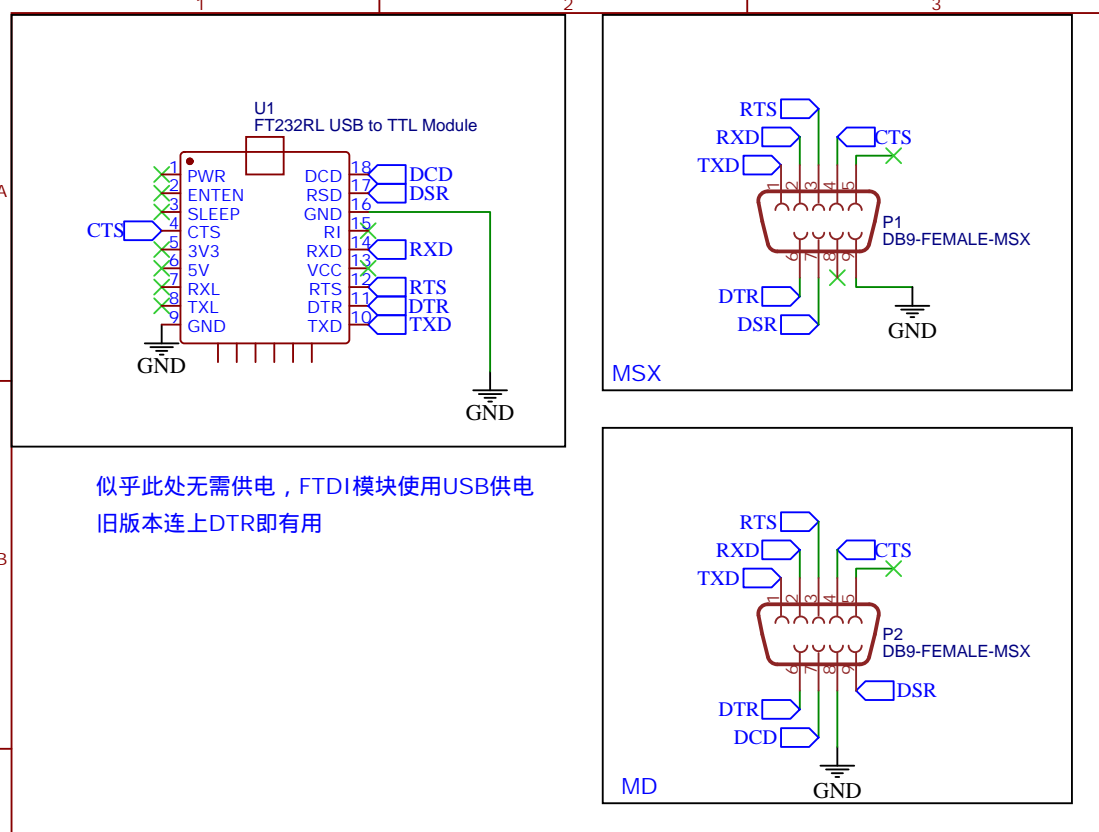
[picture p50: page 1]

FT232RL USB to TTL Module

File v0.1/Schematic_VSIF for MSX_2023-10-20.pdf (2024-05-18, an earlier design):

## MSX

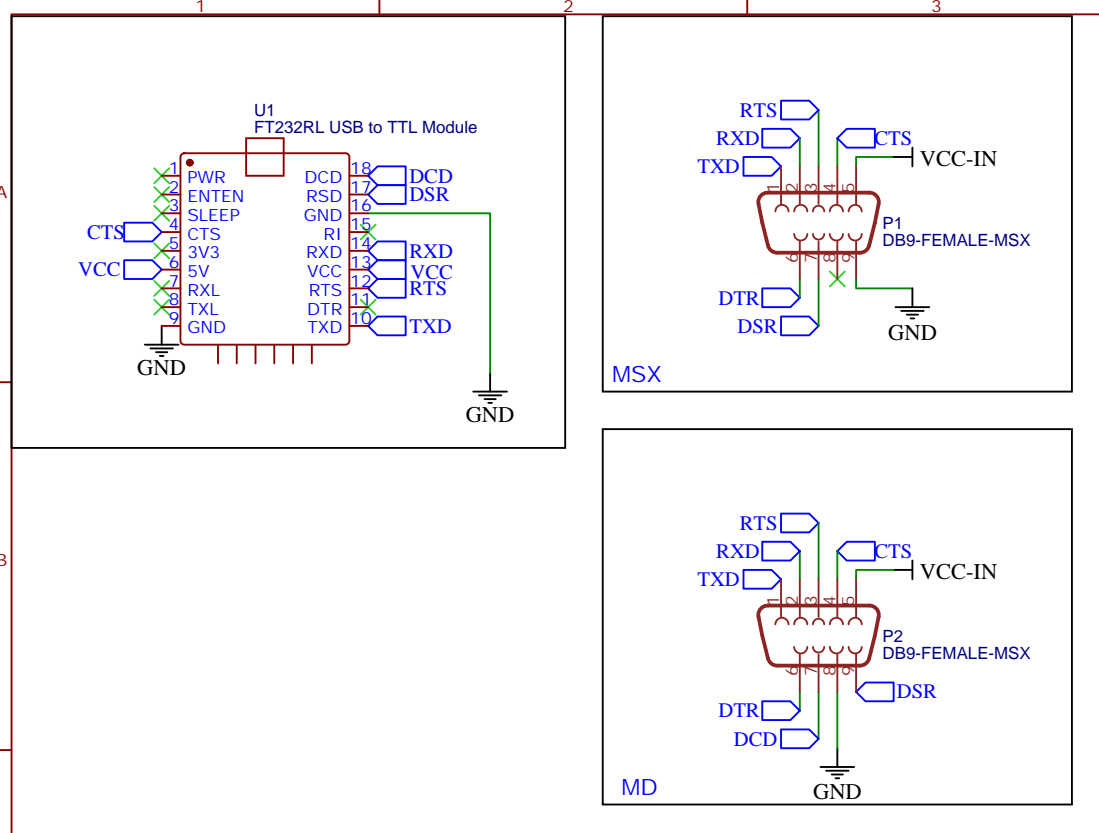
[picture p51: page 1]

FT232RL USB to TTL Module

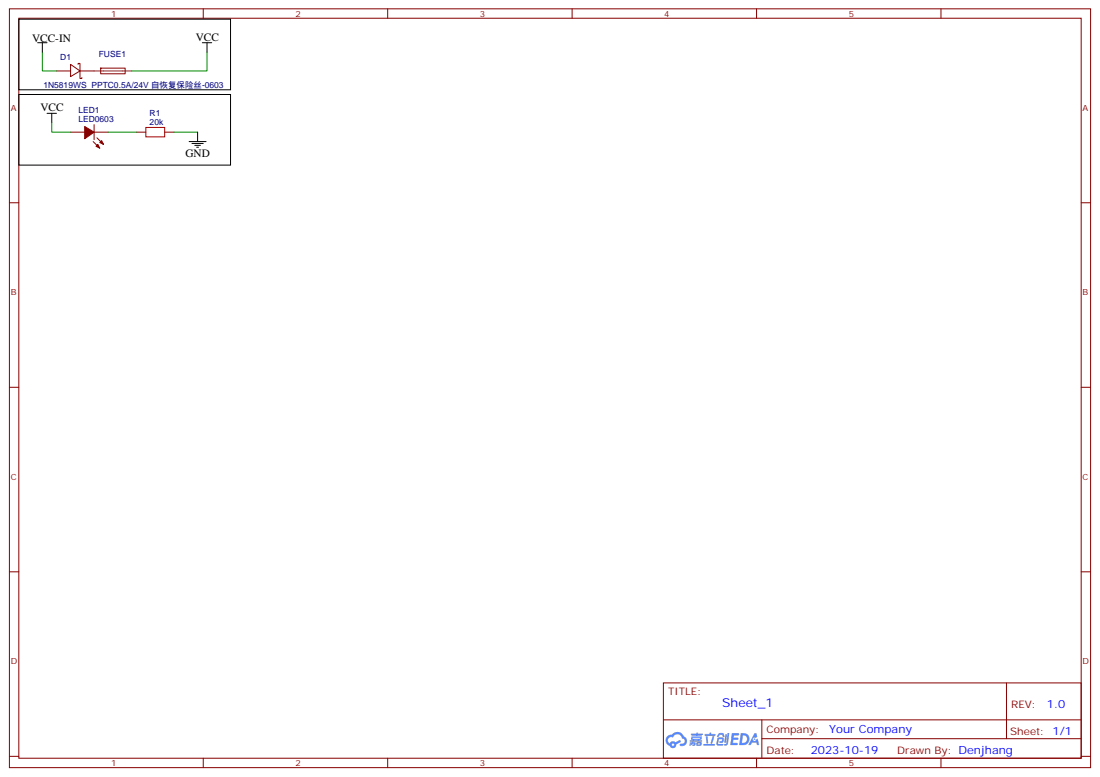
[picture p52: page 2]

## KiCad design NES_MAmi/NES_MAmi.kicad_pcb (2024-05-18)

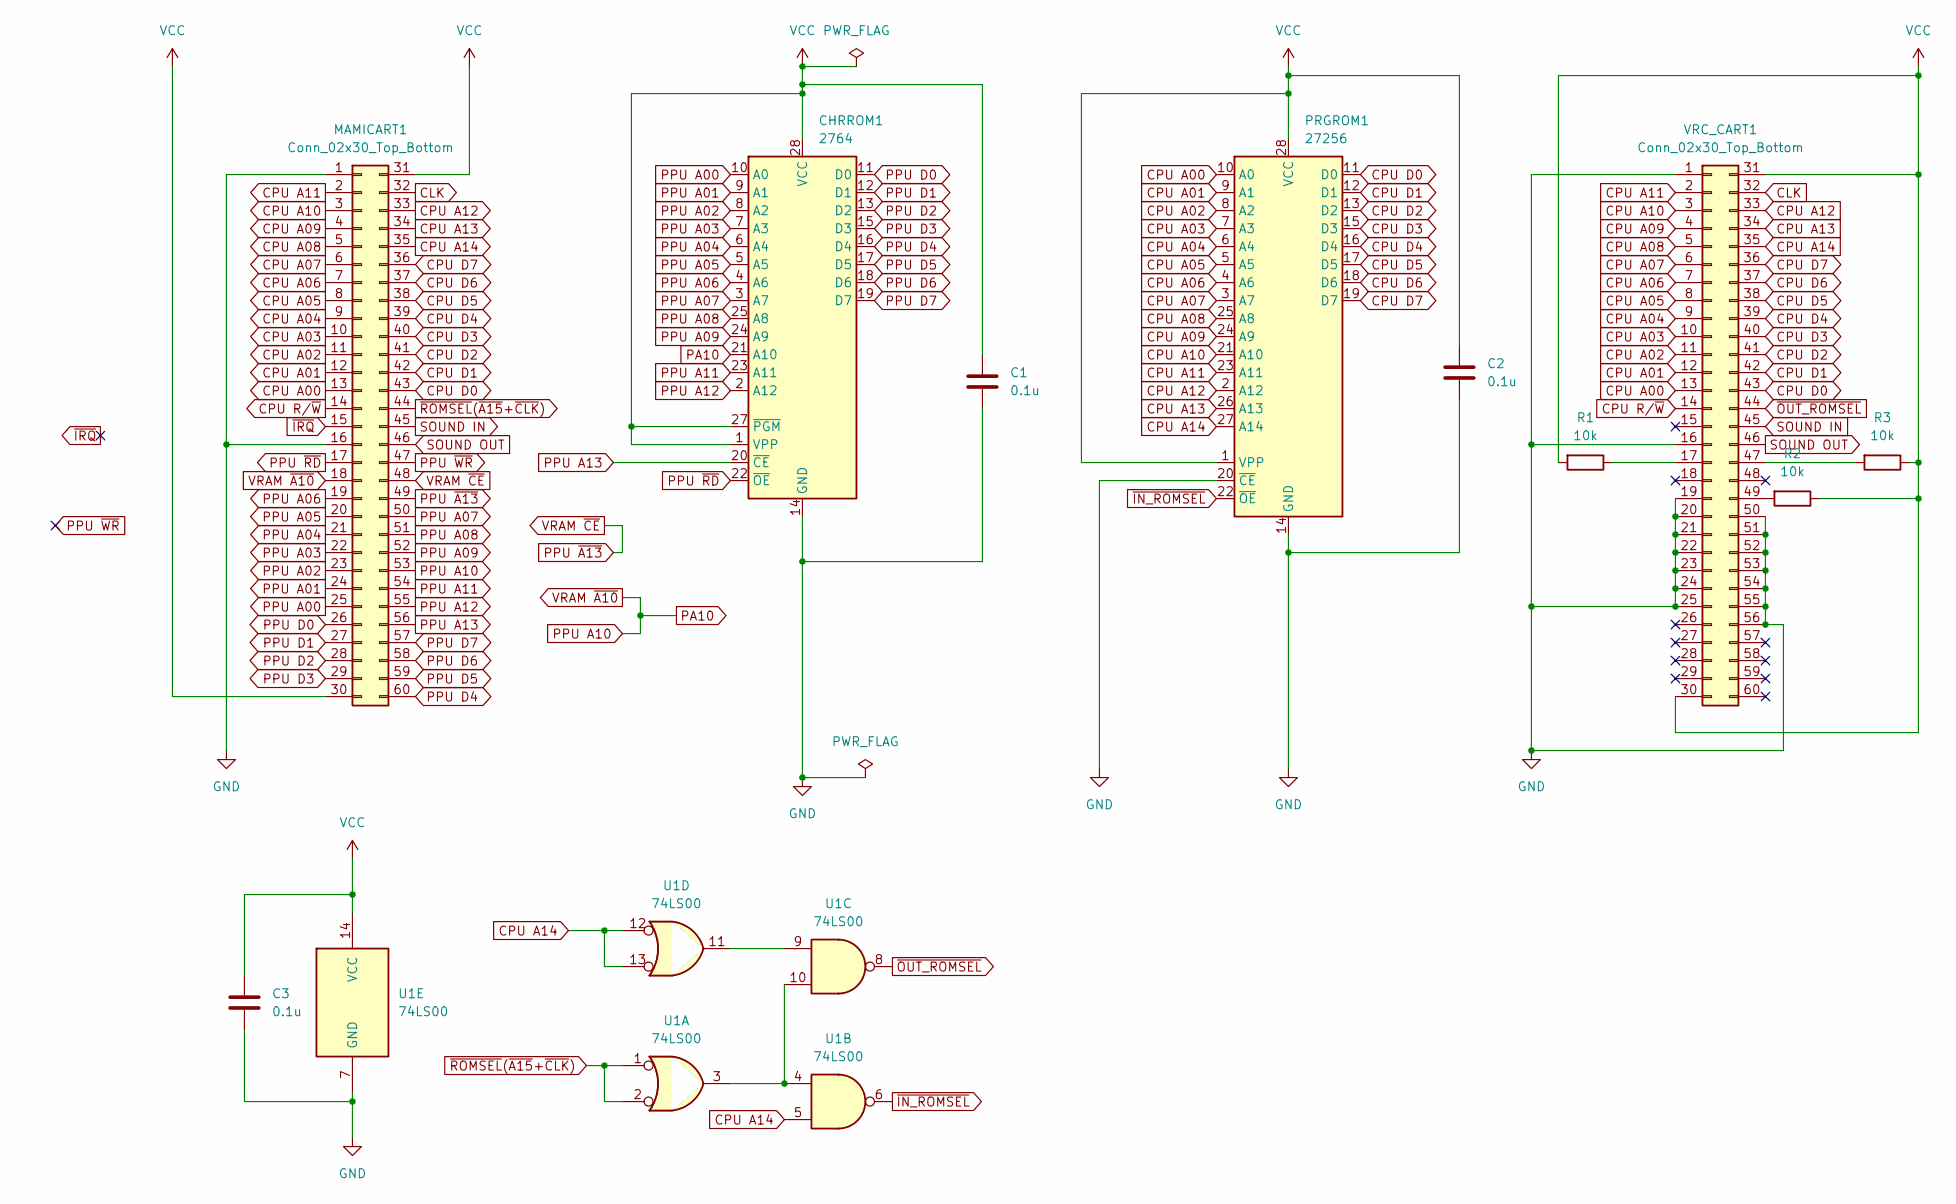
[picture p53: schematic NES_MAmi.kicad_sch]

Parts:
C1, C2, C3: 0.1u; C_Disc_D6.0mm_W2.5mm_P5.00mm
CHRROM1: 2764; DIP-28_W15.24mm
MAMICART1: Conn_02x30_Top_Bottom; FC_cardedge_60p
PRGROM1: 27256; DIP-28_W15.24mm
R1, R2, R3: 10k; R_Axial_DIN0207_L6.3mm_D2.5mm_P7.62mm_Horizontal
U1: 74LS00; DIP794W45P254L1969H508Q14
VRC_CART1: Conn_02x30_Top_Bottom; NES-CART-CONN

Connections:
CLK: MAMICART1.32, VRC_CART1.32
CPU A00: MAMICART1.13, PRGROM1.10 (A0), VRC_CART1.13
CPU A01: MAMICART1.12, PRGROM1.9 (A1), VRC_CART1.12
CPU A02: MAMICART1.11, PRGROM1.8 (A2), VRC_CART1.11
CPU A03: MAMICART1.10, PRGROM1.7 (A3), VRC_CART1.10
CPU A04: MAMICART1.9, PRGROM1.6 (A4), VRC_CART1.9
CPU A05: MAMICART1.8, PRGROM1.5 (A5), VRC_CART1.8
CPU A06: MAMICART1.7, PRGROM1.4 (A6), VRC_CART1.7
CPU A07: MAMICART1.6, PRGROM1.3 (A7), VRC_CART1.6
CPU A08: MAMICART1.5, PRGROM1.25 (A8), VRC_CART1.5
CPU A09: MAMICART1.4, PRGROM1.24 (A9), VRC_CART1.4
CPU A10: MAMICART1.3, PRGROM1.21 (A10), VRC_CART1.3
CPU A11: MAMICART1.2, PRGROM1.23 (A11), VRC_CART1.2
CPU A12: MAMICART1.33, PRGROM1.2 (A12), VRC_CART1.33
CPU A13: MAMICART1.34, PRGROM1.26 (A13), VRC_CART1.34
CPU A14: MAMICART1.35, PRGROM1.27 (A14), U1.5, U1.12, U1.13, VRC_CART1.35
CPU D0: MAMICART1.43, PRGROM1.11 (D0), VRC_CART1.43
CPU D1: MAMICART1.42, PRGROM1.12 (D1), VRC_CART1.42
CPU D2: MAMICART1.41, PRGROM1.13 (D2), VRC_CART1.41
CPU D3: MAMICART1.40, PRGROM1.15 (D3), VRC_CART1.40
CPU D4: MAMICART1.39, PRGROM1.16 (D4), VRC_CART1.39
CPU D5: MAMICART1.38, PRGROM1.17 (D5), VRC_CART1.38
CPU D6: MAMICART1.37, PRGROM1.18 (D6), VRC_CART1.37
CPU D7: MAMICART1.36, PRGROM1.19 (D7), VRC_CART1.36
CPU R/~W: MAMICART1.14, VRC_CART1.14
GND: C1.2, C2.2, C3.2, CHRROM1.14 (GND), MAMICART1.1, MAMICART1.16, PRGROM1.14 (GND), PRGROM1.20 (~CE), U1.7 (GND), VRC_CART1.1, VRC_CART1.16, VRC_CART1.19, VRC_CART1.20, VRC_CART1.21, VRC_CART1.22, VRC_CART1.23, VRC_CART1.24, VRC_CART1.25, VRC_CART1.50, VRC_CART1.51, VRC_CART1.52, VRC_CART1.53, VRC_CART1.54, VRC_CART1.55, VRC_CART1.56
unnamed: U1.3, U1.4, U1.10
unnamed: U1.9, U1.11
unnamed: R1.1, VRC_CART1.17
unnamed: R3.2, VRC_CART1.47
unnamed: R2.2, VRC_CART1.49
PA10: CHRROM1.21 (A10), MAMICART1.18, MAMICART1.53
PPU A00: CHRROM1.10 (A0), MAMICART1.25
PPU A01: CHRROM1.9 (A1), MAMICART1.24
PPU A02: CHRROM1.8 (A2), MAMICART1.23
PPU A03: CHRROM1.7 (A3), MAMICART1.22
PPU A04: CHRROM1.6 (A4), MAMICART1.21
PPU A05: CHRROM1.5 (A5), MAMICART1.20
PPU A06: CHRROM1.4 (A6), MAMICART1.19
PPU A07: CHRROM1.3 (A7), MAMICART1.50
PPU A08: CHRROM1.25 (A8), MAMICART1.51
PPU A09: CHRROM1.24 (A9), MAMICART1.52
PPU A11: CHRROM1.23 (A11), MAMICART1.54
PPU A12: CHRROM1.2 (A12), MAMICART1.55
PPU A13: CHRROM1.20 (~CE), MAMICART1.56
PPU D0: CHRROM1.11 (D0), MAMICART1.26
PPU D1: CHRROM1.12 (D1), MAMICART1.27
PPU D2: CHRROM1.13 (D2), MAMICART1.28
PPU D3: CHRROM1.15 (D3), MAMICART1.29
PPU D4: CHRROM1.16 (D4), MAMICART1.60
PPU D5: CHRROM1.17 (D5), MAMICART1.59
PPU D6: CHRROM1.18 (D6), MAMICART1.58
PPU D7: CHRROM1.19 (D7), MAMICART1.57
PPU ~A13: MAMICART1.48, MAMICART1.49
PPU ~RD: CHRROM1.22 (~OE), MAMICART1.17
PPU ~WR: MAMICART1.47
SOUND IN: MAMICART1.45, VRC_CART1.45
SOUND OUT: MAMICART1.46, VRC_CART1.46
VCC: C1.1, C2.1, C3.1, CHRROM1.1 (VPP), CHRROM1.27 (~PGM), CHRROM1.28 (VCC), MAMICART1.30, MAMICART1.31, PRGROM1.1 (VPP), PRGROM1.28 (VCC), R1.2, R2.1, R3.1, U1.14 (VCC), VRC_CART1.30, VRC_CART1.31
~IN_ROMSEL: PRGROM1.22 (~OE), U1.6
~IRQ: MAMICART1.15
~OUT_ROMSEL: U1.8, VRC_CART1.44
~ROMSEL(~A15+~CLK): MAMICART1.44, U1.1, U1.2

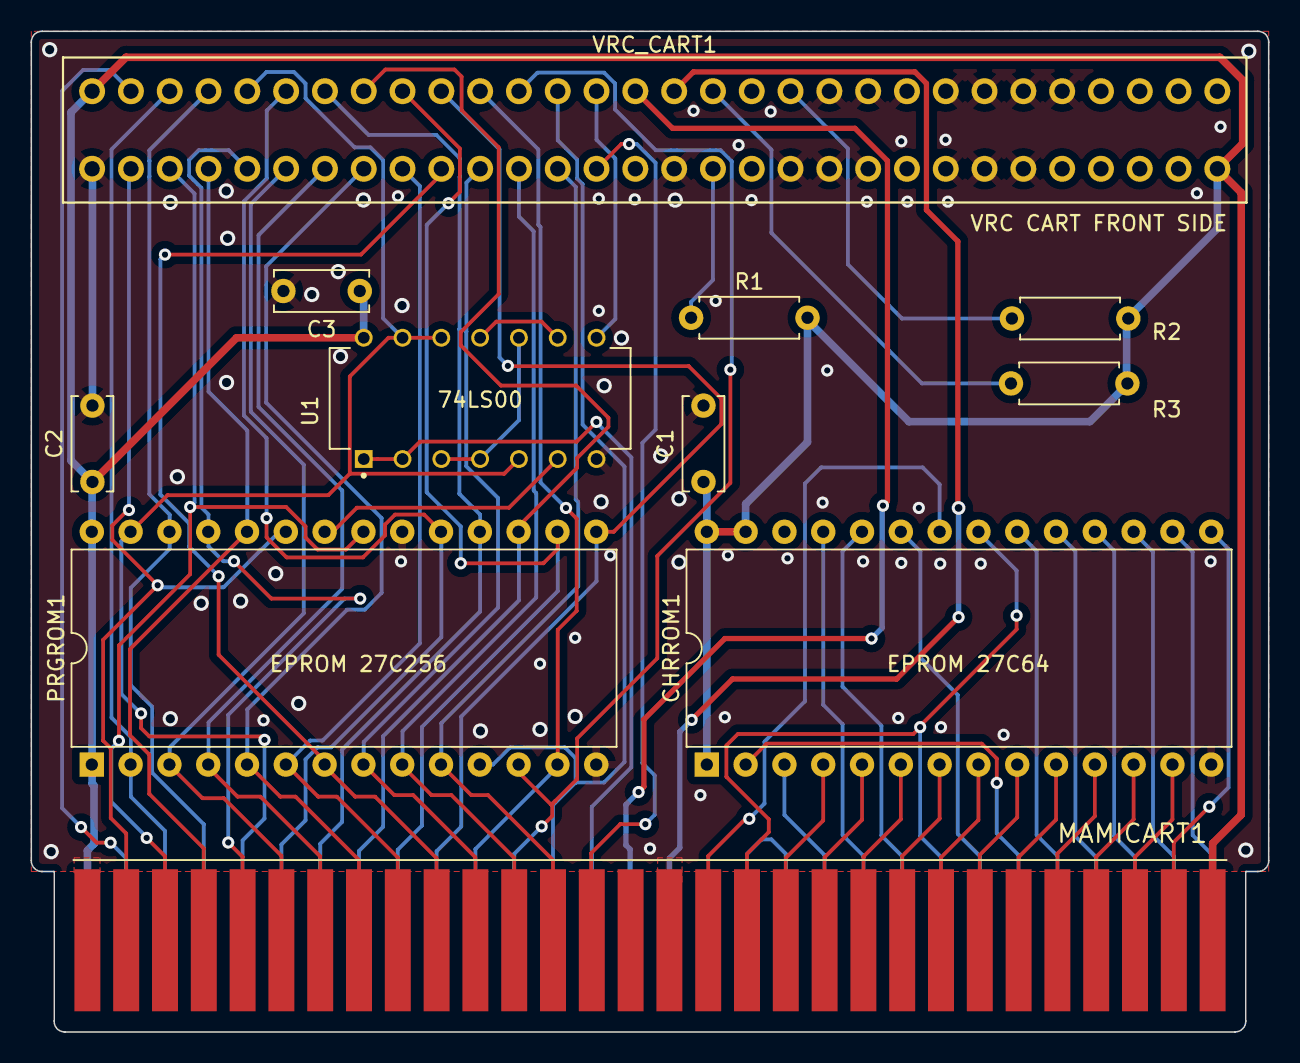
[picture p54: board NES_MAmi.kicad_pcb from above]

Board: 2 copper layers, 81.0 x 65.5 mm, 11 parts (0 on the bottom side), 61 nets.

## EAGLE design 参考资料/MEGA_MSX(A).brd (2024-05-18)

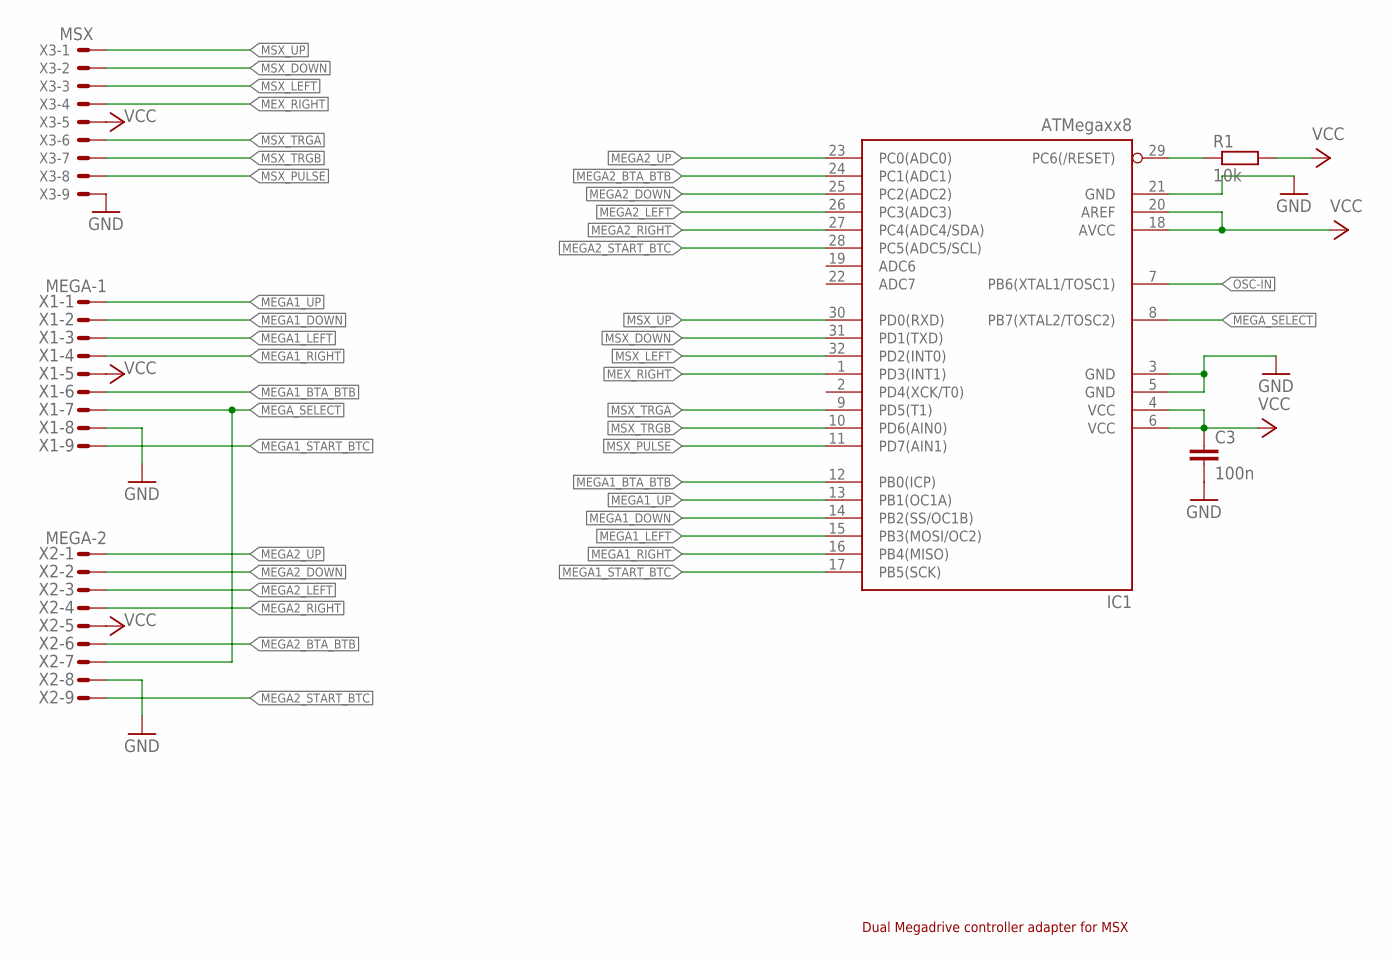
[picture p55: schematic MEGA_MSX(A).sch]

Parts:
C3: 100n; C0805
IC1: ATMegaxx8; TQFP32-08
R1: 10k; R0805
X1: MEGA-1; M09D
X2: MEGA-2; M09D
X3: MSX; 22-23-2091

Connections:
!RESET: IC1.29 (PC6(/RESET)), R1.1
GND: C3.2, IC1.3 (GND), IC1.5 (GND), IC1.21 (GND), X1.8, X2.8, X3.9
MEGA1_BTA_BTB: IC1.12 (PB0(ICP)), X1.6
MEGA1_DOWN: IC1.14 (PB2(SS/OC1B)), X1.2
MEGA1_LEFT: IC1.15 (PB3(MOSI/OC2)), X1.3
MEGA1_RIGHT: IC1.16 (PB4(MISO)), X1.4
MEGA1_START_BTC: IC1.17 (PB5(SCK)), X1.9
MEGA1_UP: IC1.13 (PB1(OC1A)), X1.1
MEGA2_BTA_BTB: IC1.24 (PC1(ADC1)), X2.6
MEGA2_DOWN: IC1.25 (PC2(ADC2)), X2.2
MEGA2_LEFT: IC1.26 (PC3(ADC3)), X2.3
MEGA2_RIGHT: IC1.27 (PC4(ADC4/SDA)), X2.4
MEGA2_START_BTC: IC1.28 (PC5(ADC5/SCL)), X2.9
MEGA2_UP: IC1.23 (PC0(ADC0)), X2.1
MEGA_SELECT: IC1.8 (PB7(XTAL2/TOSC2)), X1.7, X2.7
MEX_RIGHT: IC1.1 (PD3(INT1)), X3.4
MSX_DOWN: IC1.31 (PD1(TXD)), X3.2
MSX_LEFT: IC1.32 (PD2(INT0)), X3.3
MSX_PULSE: IC1.11 (PD7(AIN1)), X3.8
MSX_TRGA: IC1.9 (PD5(T1)), X3.6
MSX_TRGB: IC1.10 (PD6(AIN0)), X3.7
MSX_UP: IC1.30 (PD0(RXD)), X3.1
OSC-IN: IC1.7 (PB6(XTAL1/TOSC1))
VCC: C3.1, IC1.4 (VCC), IC1.6 (VCC), IC1.18 (AVCC), IC1.20 (AREF), R1.2, X1.5, X2.5, X3.5

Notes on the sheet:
Dual Megadrive controller adapter for MSX

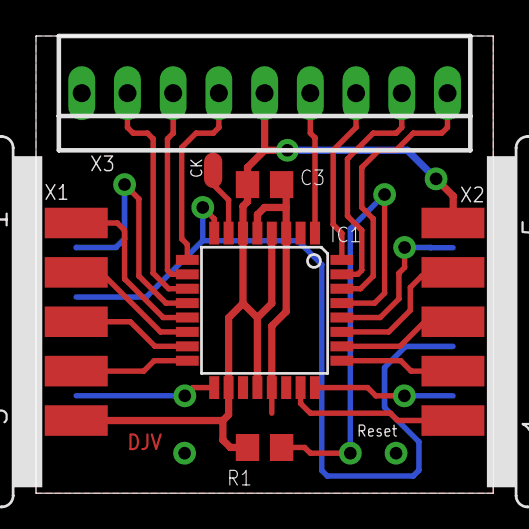
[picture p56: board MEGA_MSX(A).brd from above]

Board: 2 copper layers, 25.4 x 25.4 mm, 6 parts (0 on the bottom side), 23 nets.
